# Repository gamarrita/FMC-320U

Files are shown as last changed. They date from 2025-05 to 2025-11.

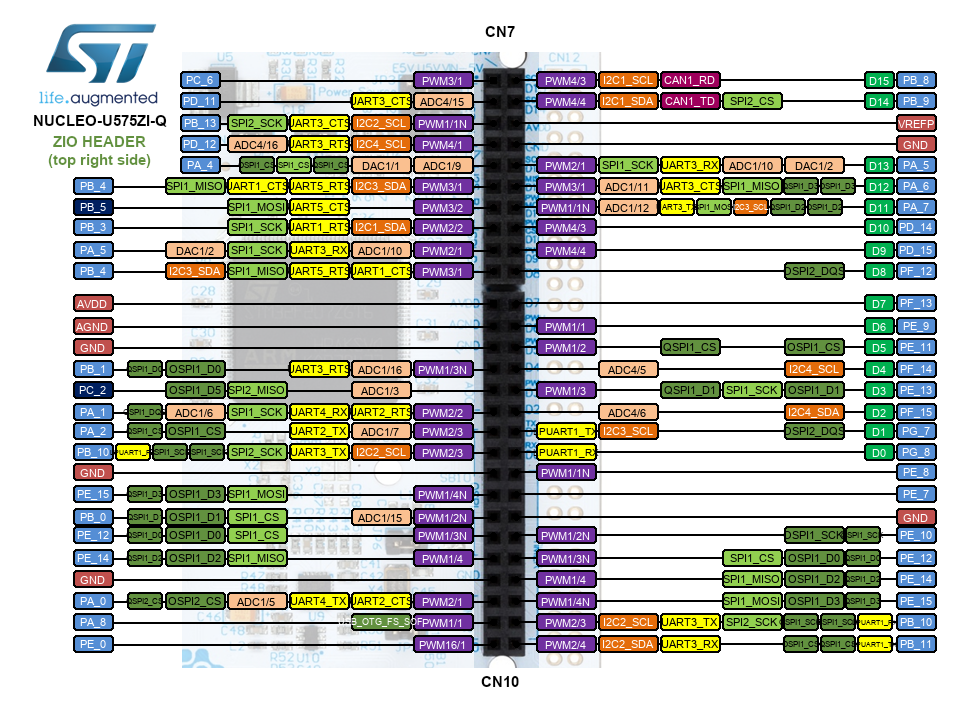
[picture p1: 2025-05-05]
docs/componentes/STM32/nucleo_cn_7_10.png

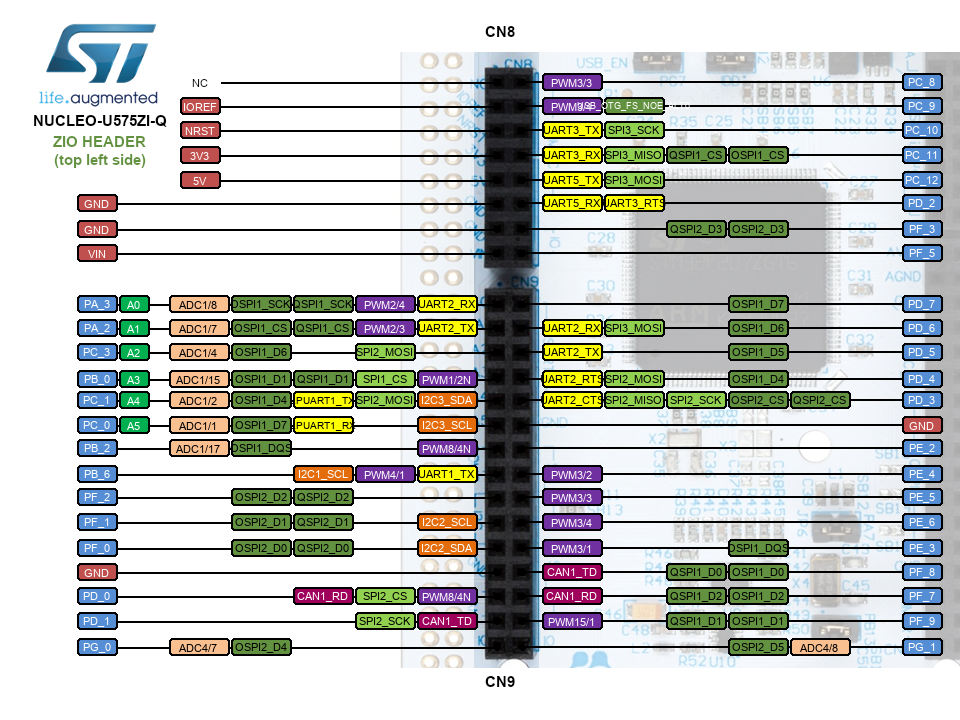
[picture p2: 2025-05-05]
docs/componentes/STM32/nucleo_con_8_9.png

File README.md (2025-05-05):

# FMC-320U: Autonomous Flow Computer

Overview
FMC-320U is an advanced autonomous flow computer designed for precise flow
measurement in industrial applications. It integrates with sensors that emit
pulse signals, processes data in real-time, and provides reliable analytics for
flow monitoring. The system is optimized for ultra-low power consumption,
making it ideal for remote and unattended operations.

Features
- Autonomous Operation: Works independently without requiring external
  computing resources.
- Ultra-Low Power Consumption: Operates with a power consumption of less than
  50µA, making it highly efficient for battery-powered applications. 
- Real-Time Data Processing: Captures and analyzes pulse-based sensor inputs
  efficiently using ThreadX RTOS for optimized multitasking.
- Industrial-Grade Reliability: Ensures accurate and stable performance under
  demanding conditions.
- IoT Capabilities: Supports Wi-Fi and Bluetooth connectivity, enabling remote
  monitoring and data transmission.
- High-Performance Microcontroller: Powered by an STM32F575 microcontroller,
  offering robust computational performance and peripherals for industrial
  applications.
- Data Logging: Includes data logging capabilities to store historical flow
  data for analysis and trend monitoring.
- Modular & Extensible: Easily adaptable to various industrial flow
  measurement scenarios.

Hardware & Firmware
The FMC-320U is built on a robust embedded system, utilizing an STM32F575
ultra-low-power microcontroller optimized for long-term operation. The
firmware is based on ThreadX RTOS, ensuring efficient task management and
real-time data acquisition. Additionally, its IoT features allow seamless
integration with cloud-based monitoring systems.

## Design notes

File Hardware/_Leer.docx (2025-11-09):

Modelo A: formato de PCB rectangular, para cajas EJB0 de la mara TheExZone.

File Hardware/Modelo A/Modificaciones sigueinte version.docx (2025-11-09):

Mejoras de V1R1R1 a V1R2R1 (FINALIZADA)

BUG 1.

Comportamiento: FMC-320U-A2, no alimenta correctamente FMC-320-A1.

Descripción: R2 debería ser de 0 Ohms pero se colocó de 2.49k Ohms, el componente original tenía mal cargado el desginator, error repetido varias veces al crear un componente duplicando uno similar, PCBWAY nota un problema con el footprint y pregunta por cual cambiar, ahí se le pasa un numero de parte erróneo, se corrige un error con otro error.

Solución propuesta: Verificar componente en librería, ver si es necesario actualizar schematic y PCB. Cambiar resistor por uno de 0 Ohms.

Estado: Solucionado

BUG 2.

Comportamiento: el armador del PCB no puede montar componentes x,y,z (completar) los comprados son 0603 y los que se necesitan son 0805.

Descripción: Los componentes (listar componentes) no existían en la biblioteca de Yageo, se los crearon duplicando otros componentes, pero en lugar de duplicar a partir de componentes 0805 se los duplico usando componentes 0603. Notar que al duplicar un componente se deben cambiar necesariamente al menos dos campos, el “Desing Item ID”, pero además el Manufacture “Part Number”, que es el que luego aparece en el BOM.

Solución propuesta: recopilar los ID de números de parte con problemas, corregir librería yageo, actualizar componentes modificados desde la nueva versión de librería (puede que ya este hecho, verificar).

Estado: Solucionado.

BUG 3.

Comportamiento: no funciona el front-end de la salida de pulsos.

Descripción: integrado U1 sin alimentación, el pin 7 que es DVDD del integrado no se conectó.

Solución propuesta: Agregar conexión entre pin 7 u DVDD en el esquemático y routear en PCB. Para las placas prototipos soldar cable entre pin 7 del IC y DVDD

Estado: Solucionado.

BUG 4.

Comportamiento: la corriente en el RTD no es la esperada

Descripción: R16 es 200k cuando debería ser de 100k.

Solución propusta: cambiar el valor de R16 en el laboratorio, verificar funcionamiento, si funciona como lo esperado hacer el cambio en Altium para schematic y PCB.

Estado: Solucionado, se está usando un IC dedicado a la lectura de temperatura.

BUG 5.

Comportamiento: Placa no encaja en gabinete FM-520

Descripción: Los agujeros de fijación están desplazados con respecto a su predecesor FM-500.

Solución: posicionar nuevamente los agujeros de fijación.

Estado: Solucionado, se cambió dimensión de placa, no tiene compatibilidad con antiguo montaje.

BUG 6.

Comportamiento: No se puede medir el consumo del computador correctamente con el programador conectado.

Descripciones: ST-LINK suma 500uA de consumo al computador.

Solución: colocar resistor de cero ohms, solo se colocará en placas de producción.

Estado: Solucionado, se usa una línea exclusiva de alimentación para el ST.LINK.

BUG 7.

Cambiar a baterías AA. Esto se podría considerar como una mejora, pero es de tal importancia que se lo considera un BUG haber usado AAA.

Estado: Solucionado, se cambió a AA.

MEJORA 1.

Descripción: implementar puerto estándar para analizador lógico, o bits + VCC + GND

Solución propuesta: cambiar el valor de R16 en el laboratorio, verificar funcionamiento, si funciona como lo esperado hacer el cambio en Altium para esquemático y PCB.

Estado: Desestimado, se tiene un puerto para ajuste, PD1 a PD4, se lo puede usar para este propósito, hay posibilidad que dada GPIO cumpla doble función, lectura de configuración y señalización o expandir.

MEJORA 2.

Los colores de los LED deben ser:

- LED_1_ERROR usar color rojo
- LED_2 _ACTIVE usar color azul
- LED_3_SIGNAL_1 usar color verde

Estado: Solucionado.

MEJORA 3.

Solo las placas para prototipo tienen lo resistores colocados para los LED. Buscar método para contemplar esto en producción.

Estado: Solucionar por software, los PD1 a PD4 configuran si se prenden o no los LEDs.

MEJORA 4.

Conexión de teclado no tiene acceso, queda bloqueado por la placa 2.

Estado: Solucionado, se cambió a conector a 90°.

VERSIONE ACTUAL

FMC-320U-A1 V1R2R1

FMC-320U-A2 V1R2R1

EMC-3080 V1R1R1

SIGUIENTE VERSIÓN

FMC-320U-A1

FMC-320U-A2

EMC-3080

MODIFICACIÓN #1

Tipo: mejora.

Descripción: para los GPIO usados para los pulsadores externos, incluir filtro RC.

Comportamiento actual:

Comportamiento esperado:

MODIFICACIÓN #2

Tipo: mejora

Descripción: usar borneras para para pulsadores externos.

Comportamiento actual:

Comportamiento esperado:

MODIFICACIÓN #3

Para los GPIO usados para pulsoadores extenos, buscar re-incorprar los dos GPIO perdidos, destinados a configuración y ahora se usan como pulsadores.

MODIFICACIÓN #4

- Lineas RX y TX de UART con pull-up o pull-down. EL

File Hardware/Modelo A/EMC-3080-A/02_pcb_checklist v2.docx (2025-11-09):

Verificación final.

- Repour all polygons -> OK
- Validate PCB Project -> OK
- Verificar que el PCB y el esquemático estén sincronizados -> OK
- Tools -> Desing -> Rule check -> Rulse Desing Rule Check -> OK

Si cualquiera de los anteriores da mal hay volver a iniciar. Si se al verificar cualquiera de los siguientes apartados da mal, volver a iniciar esta verificación.

CARPETAS Y ARCHIVOS.

- Revisar que las carpetas tengan nombres consistentes -> OK
- Revisar que los archivos tengan nombres consistentes -> OK

CREAR EL BOM Y VERIFICAR.

- Manufacturer -> OK
- Manufacturer Part Number -> OK
- Temperatura mínima -> NO APLICA
- Temperatura máxima -> NO APLICA
- Main Supplier ->
- Target Price ->
- No hay dobles valores en ningún campo -> OK

Advertencia: “Design item ID” debe ser el mismo que el Manufacturer part number

TRAZABILIDAD Y DATOS PRINCIPALES.

- El PCB con bordes delimitador en top coutyard -> OK
- Logo de la empresa -> OK
- Legendas de advertencias y peligro -> NO APLICA
- Correo y web de la empresa -> OK
- Nombre de la placa -> OK
- Número de serie, versión y revisión -> OK
- Área para número de serie -> NO APLICA
- Numero de lote -> OK
- Area para re-work -> NO APLICA
- Área para control de calidad -> NO APLICA
- Medidas de la placa en mechanical layer -> OK
- Rotulo con información en mechancal layer -> OK
- Notas sobre catodos, polaridades, etc. en mechanial layers -> OK

TOP Y BOTTOM OVERLAY.

- Designator : tamaño sugerido 1.25mm(alto)/0.25mm(grosor). Para textos que no estén horizontal usar solo un sentido vertical, sugerido arriba hacia abajo. El tamaño de 1.0mm(alto)/0.2mm(grosor) también es aceptable.
- Designators cerca de los componentes.
- IC con pin 1 claramente marcado

Los siguientes puntos de verificación se deben hacer sobre una planilla Excel que controlo cada componente.

Puertos de comunicación:

- Conexión de RX y TX cruzadas.
- Resistores de terminación calculados.
- Resistores en serie con líneas de transmisión con alto rise time y baja tasa de transferencia. Esto también aplica para comparadores y otras líneas que puedan mantenerse como sistema de parámetros concentrados.

Montaje

- Elementos mecánicos incluidos con sus modelos 3D.
- Gabinete y modelo 3D incluido

Diseño.

- Se usaron reglas estándar del fabricante -> OK
- Reglas de diseño al menos un 15% por encima de las del fabricante. -> OK
- Circuito de parámetros concentrados -> OK
- Todas las conexiones a GND con via GND copper pour -> OK
- Vías con suficiente capacidad de corriente ->
- Pistas con suficiente capacidad de corriente ->
- Componentes sin excesivo aumento de temperatura (check list en Excel) ->

Conectores

- Conectores inter-placas estén bien mapeados -> OK
- Pin 1 para Alimentación y pin 2 para GND (check list Excel) -> Regla obsoleta no se usa.
- Capacitores de desacople en los pines de alimentación (check list Excel) ->
- Conectores con CN (check list Excel) ->
- Jumpers con J (check list Excel) ->
- Altura de los conectores inter-placa sea la correcta (check list Excel) ->

BORNERAS USUARIO.

- Designators nombre sugerido P? (check list Excel) ->
- Designators tamaño sugerido 2mm / 0.4mm (check list Excel) ->
- Salidas marcadas (check list Excel) ->

CIRCUITOS INTEGRADOS.

- Alimentaciones -> OK
- Tierras -> OK
- Validado por nota de aplicación o uso anterior-> OK

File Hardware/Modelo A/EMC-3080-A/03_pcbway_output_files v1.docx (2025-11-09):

ESTE DOCUMENTO MUESTRA COMO SE PREPARAN LOS ARCHIVOS PARA ENVIAR A PCBWAY

Copiar trunk a tag, eliminar archivos no necesarios o los de salida previamente generados.

Copiar carpeta Sources

Se deben generar tres salidas:

Gerbers y Drills para PCBWAY van juntos.

Se utilizan en la fabricación del PCB. Se generan por separado, pero se comprimen en un único archivo. Links de referencia:

https://www.pcbway.es/helpcenter/technical_support/Generate_gerber_file_from_Altium.html

Centroid files (Pick&Place).

Se utilizan para la fabricación del PCB. Se comprimen junto con los gerbres

https://www.pcbway.com/helpcenter/technical_support/How_to_create_a_Centroid_File_from_Eagle__Altium_Sprint_Layout_and_ORCAD_.html

Generar Gerbers.

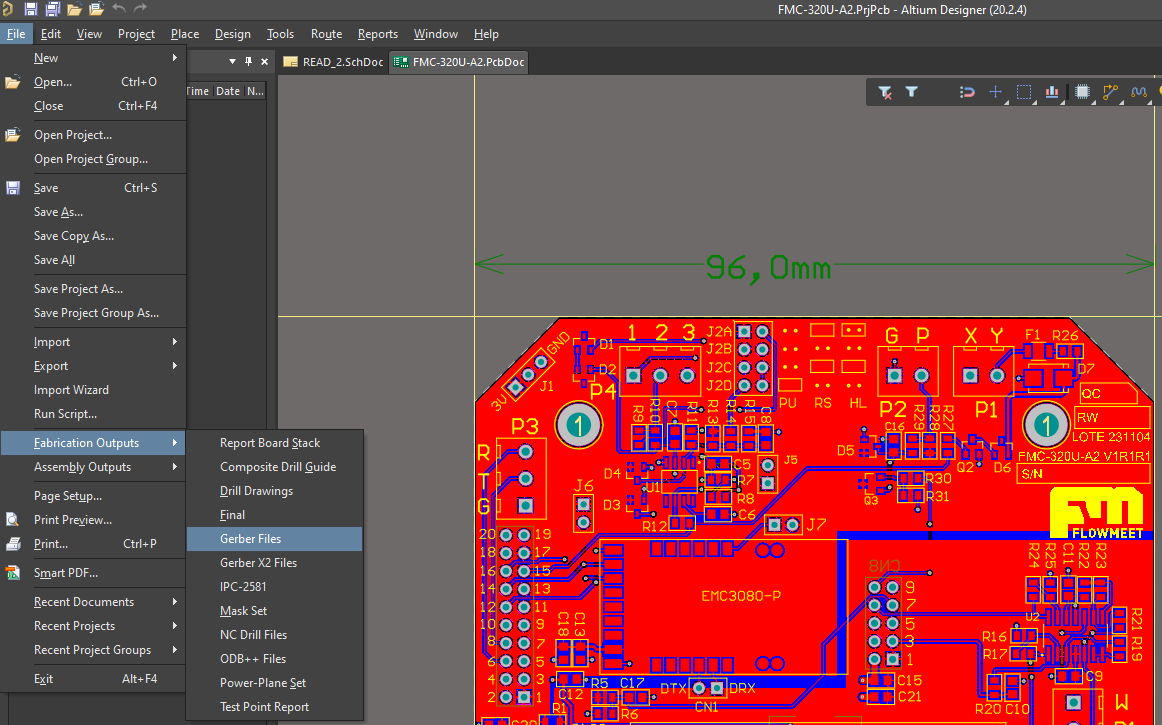
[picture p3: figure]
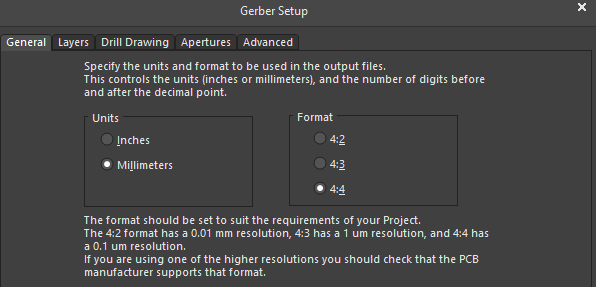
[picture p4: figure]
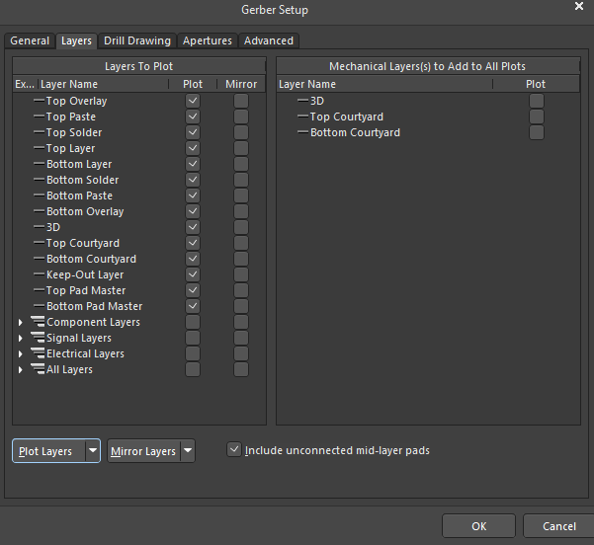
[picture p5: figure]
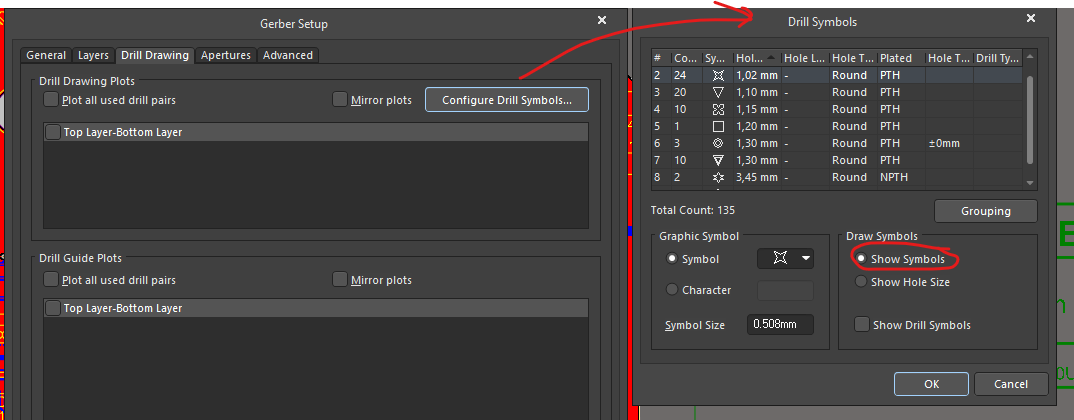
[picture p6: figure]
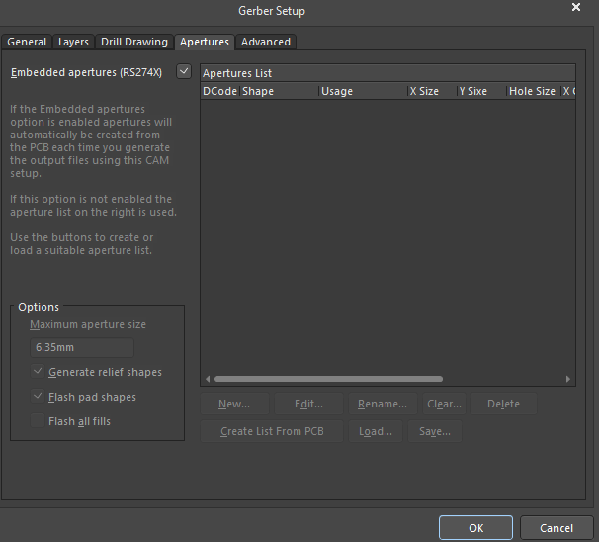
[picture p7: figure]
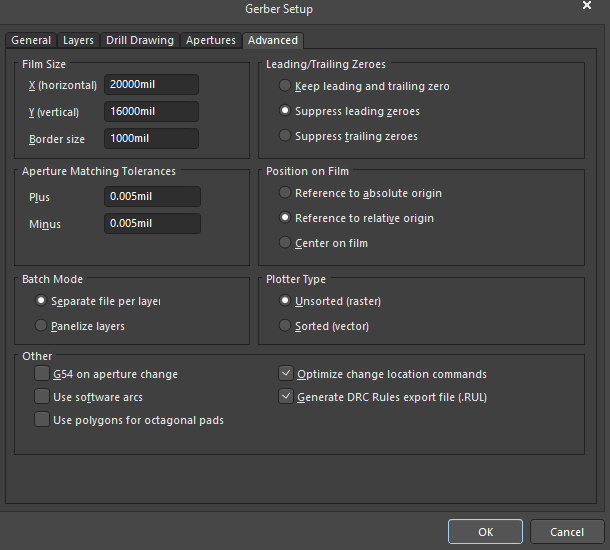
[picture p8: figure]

Generar Drills.

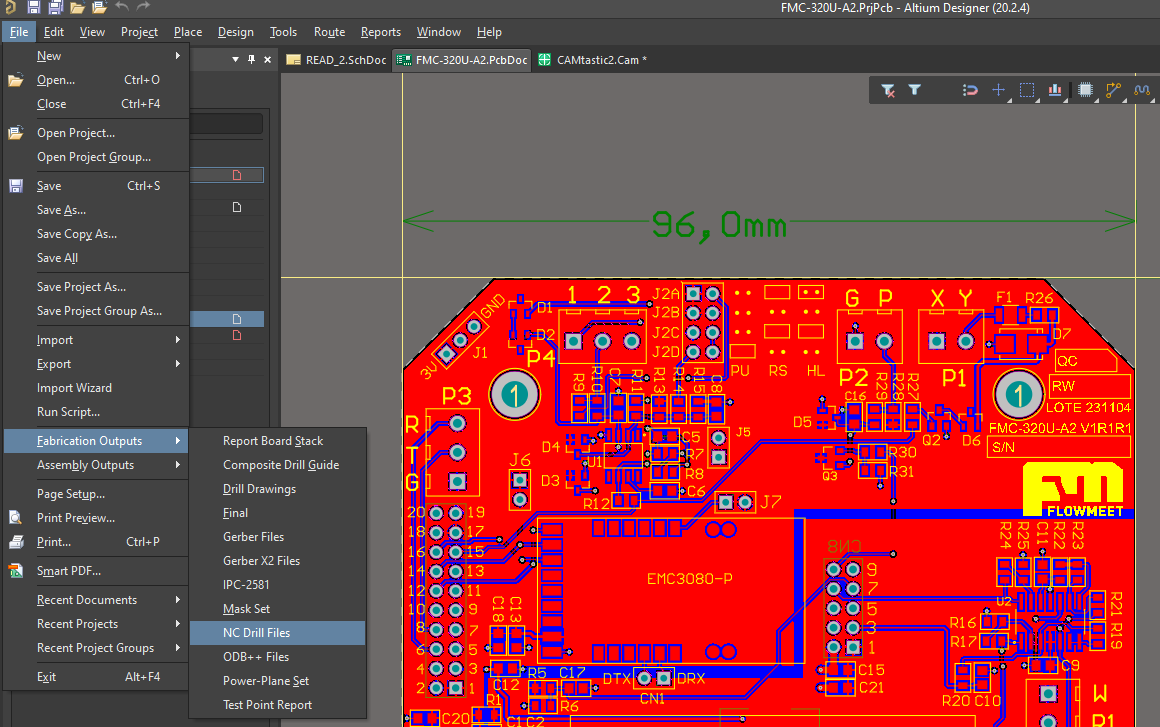
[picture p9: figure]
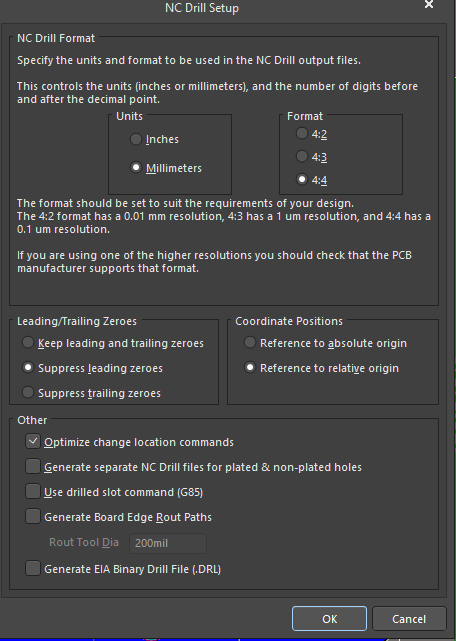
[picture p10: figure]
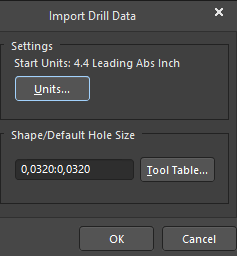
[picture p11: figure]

Pick&Place

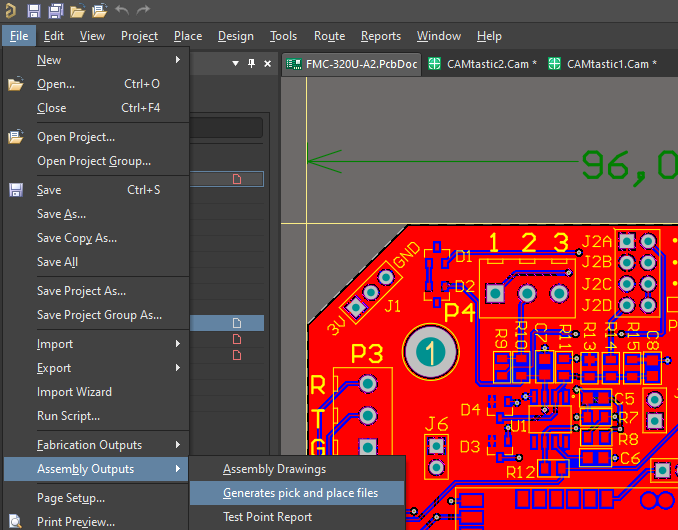
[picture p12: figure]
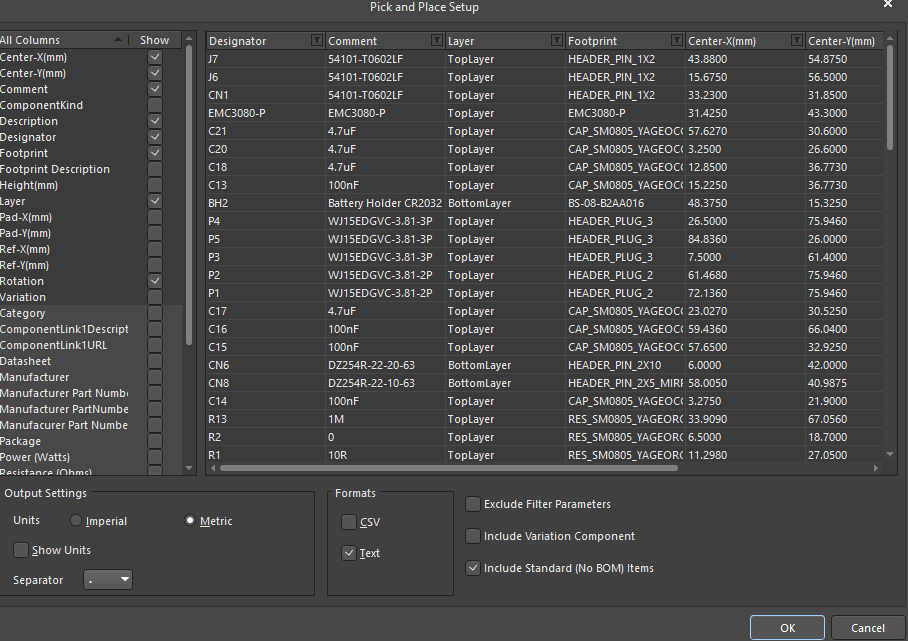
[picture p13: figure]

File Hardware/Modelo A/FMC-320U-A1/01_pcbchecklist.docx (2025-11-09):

Verificación final.

- Repour all polygons -> LISTO
- Validate PCB Project -> LISTO
- Verificar que el PCB y el esquemático estén sincronizados -> LISTO
- Tools -> Desing -> Rule check -> Rulse Desing Rule Check -> LISTO

Si cualquiera de los anteriores da mal hay volver a iniciar. Si se al verificar cualquiera de los siguientes apartados da mal, volver a iniciar esta verificación.

Carpetas y archivos.

- Revisar que las carpetas tengan nombres consistentes -> LISTO
- Revisar que los archivos tengan nombres consistentes -> LISTO

Trazabilidad y datos principales

- Logo de la empresa -> LISTO
- Legendas de advertencias y peligro -> NO APLICA
- Correo y web de la empresa -> NO APLICA
- Nombre de la placa -> LISTO
- Número de serie, versión y revisión -> LISTO
- Área para número de serie -> LISTO
- Numero de lote -> LISTO
- Area para re-work -> LISTO
- Área para control de calidad -> LISTO

Top y Bottom Overlay.

- Designator 3en tamaño 1.25mm(alto)/0.25mm(grosor). Para textos que no estén horizontal usar solo un sentido vertical, sugerido arriba hacia abajo.
- Designators cerca de los componentes.
- IC con pin 1 claramente marcado

Montaje

- Incluir tornillos, arandelas, separadores y tuercas, verificar que haya suficiente espacio para el montaje.
- Incluir modelo 3D del gabinete.

Diseño.

- Siempre que sea posible trabajar con las reglas estándar del fabricante. Apártese de esto requiere autorización.
- Ajustar las reglas de diseño un 15% por encima de las del fabricante. Solo usar espacio o grosores igual las mínimas estándar del fabricante si es totalmente necesario.
- Verificar si se esta trabajando con un circuito de parámetros distribuidos o concentrados.
- En parámetros concentrados como norma general usar lo mayor posibles componentes SMD, routeado mayormente en lado top y bottom con buen copper pour de GND. Lado top puede requerir copper pour para las alimentaciones.
- Todas las conexiones a GND con via GND copper pour.
- Vías con suficiente capacidad de corriente.
- Pistas con suficiente capacidad de corriente.
- Componentes sin excesivo aumento de temperatura.

verificación de parámetros concentrado.

No hay en esta placa.

Conectores

- Verificar que conectores inter-placas estén bien mapeados.
- Como regla general usar pin 1 para Alimentación y pin 2 para GND.
- Capacitores de desacople en los pines de alimentación.
- Conectores con CN.
- Jumpers con J.
- Verificar que la altura de los conectores inter-placa sea la correcta

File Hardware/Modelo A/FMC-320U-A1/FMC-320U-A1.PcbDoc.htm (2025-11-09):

Reporting Options

# File in Newer Format

Date | : | 30/11/2024
Time | : | 10:57:01
Filename | : | D:\FLOWMEET Dropbox\flowmeet\ID\Electronica\Equipos\FMC-320U\hardware\altium\model_a\trunk\FMC-320U-A1\FMC-320U-A1.PcbDoc

Version | Warning
Release 23.6 | CAUTION - The PCB document contains Footprint parameters. These will be lost when opening the document in a version of Altium Designer that does not support this functionality.

This file was generated by a later version of the software

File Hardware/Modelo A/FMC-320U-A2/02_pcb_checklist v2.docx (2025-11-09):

Modificaciones

28/11/2023 - DHS: agrego verificación entre Desing Item ID y Manufacturar part number

Descripcion: Este documento es check list de PCB creado en Altium Designer necesario de completar antes de enviar a fabricar a PCBWAY. Describe los pasos a seguir cuando la etapa de diseño esté terminada. Antes de iniciar el proceso de pedido de cotización se deben pasar todas las verificaciones. Este documento se debe trabajar en conjunto con el 01_components_check_list. Luego debe seguir las instrucciones del documento se ejecuta el 03_pcway_output_files, se genera la carpeta versionada y archivos para enviar al fabricante de placas.

Verificación final.

- Repour all polygons ->
- Validate PCB Project ->
- Verificar que el PCB y el esquemático estén sincronizados ->
- Tools -> Desing -> Rule check -> Rulse Desing Rule Check ->

Si cualquiera de los anteriores da mal hay volver a iniciar. Si se al verificar cualquiera de los siguientes apartados da mal, volver a iniciar esta verificación.

CARPETAS Y ARCHIVOS.

- Revisar que las carpetas tengan nombres consistentes ->
- Revisar que los archivos tengan nombres consistentes ->

CREAR EL BOM Y VERIFICAR.

- Designator ->
- Quantity ->
- Manufacturer ->
- Manufacturer Part Number ->
- Temperatura mínima ->
- Temperatura máxima ->
- Main Supplier ->
- Target Price ->

Advertencia : “Design item ID” debe ser el mismo que el Manufacturer part number.

TRAZABILIDAD Y DATOS PRINCIPALES.

- El PCB con bordes delimitador en top coutyard ->
- Logo de la empresa -> OK
- Legendas de advertencias y peligro -> NO APLICA
- Correo y web de la empresa -> NO APLICA
- Nombre de la placa -> OK
- Número de serie, versión y revisión -> OK
- Área para número de serie -> OK
- Numero de lote -> OK
- Area para re-work -> OK
- Área para control de calidad -> OK
- Medidas de la placa en mechanical layer -> OK
- Rotulo con información en mechancal layer -> OK
- Notas sobre catodos, polaridades, etc. en mechanial layers -> OK

TOP Y BOTTOM OVERLAY.

- Designator : tamaño sugerido 1.25mm(alto)/0.25mm(grosor). Para textos que no estén horizontal usar solo un sentido vertical, sugerido arriba hacia abajo. El tamaño de 1.0mm(alto)/0.2mm(grosor) también es aceptable.
- Designators cerca de los componentes.
- IC con pin 1 claramente marcado

Los siguientes puntos de verificación se deben hacer sobre una planilla Excel que controlo cada componente.

Puertos de comunicación:

- Conexión de RX y TX cruzadas.
- Resistores de terminación calculados.
- Resistores en serie con líneas de transmisión con alto rise time y baja tasa de transferencia. Esto también aplica para comparadores y otras líneas que puedan mantenerse como sistema de parámetros concentrados.

Montaje

- Elementos mecánicos incluidos con sus modelos 3D.
- Gabinete y modelo 3D incluido

Diseño.

- Se usaron reglas estándar del fabricante -> OK
- Reglas de diseño al menos un 15% por encima de las del fabricante. -> OK
- Circuito de parámetros concentrados -> OK
- Todas las conexiones a GND con via GND copper pour -> OK
- Vías con suficiente capacidad de corriente ->
- Pistas con suficiente capacidad de corriente ->
- Componentes sin excesivo aumento de temperatura (check list en Excel) ->

Conectores

- Conectores inter-placas estén bien mapeados (check list Excel) ->
- Pin 1 para Alimentación y pin 2 para GND (check list Excel) ->
- Capacitores de desacople en los pines de alimentación (check list Excel) ->
- Conectores con CN (check list Excel) ->
- Jumpers con J (check list Excel) ->
- Altura de los conectores inter-placa sea la correcta (check list Excel) ->

BORNERAS USUARIO.

- Designators nombre sugerido P? (check list Excel) ->
- Designators tamaño sugerido 2mm / 0.4mm (check list Excel) ->
- Salidas marcadas (check list Excel) ->

CIRCUITOS INTEGRADOS.

- Alimentaciones ->
- Tierras ->
- Validado por nota de aplicación o uso anterior->

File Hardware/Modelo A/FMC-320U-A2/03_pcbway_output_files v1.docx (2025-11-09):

ESTE DOCUMENTO MUESTRA COMO SE PREPARAN LOS ARCHIVOS PARA ENVIAR A PCBWAY

Se hace un realese del projecto. Con los archivos generados se crea el tag.

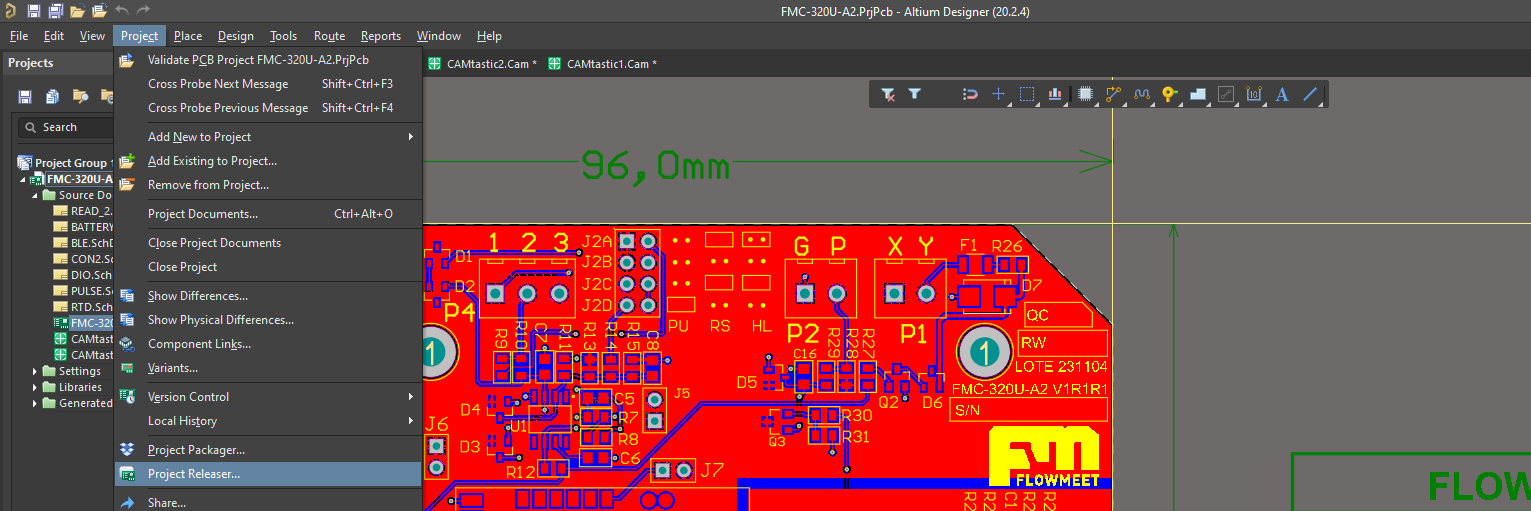
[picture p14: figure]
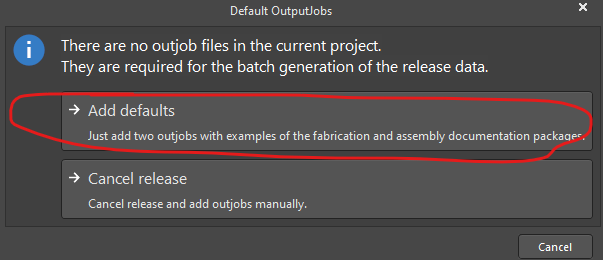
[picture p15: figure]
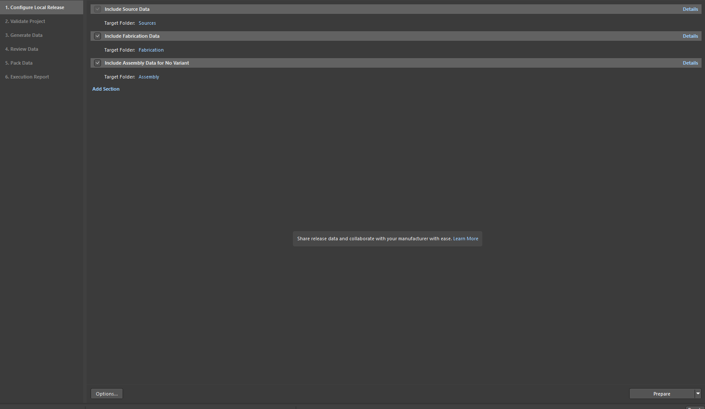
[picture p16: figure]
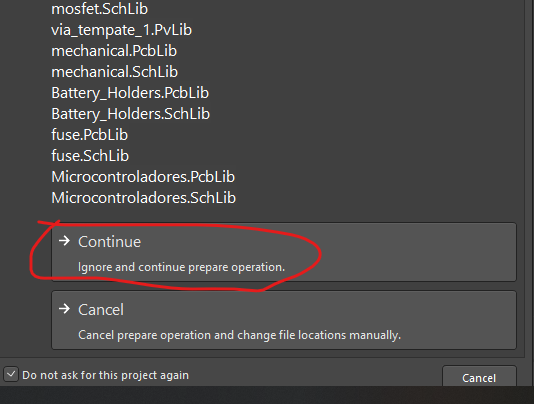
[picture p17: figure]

Copiar carpeta Sources

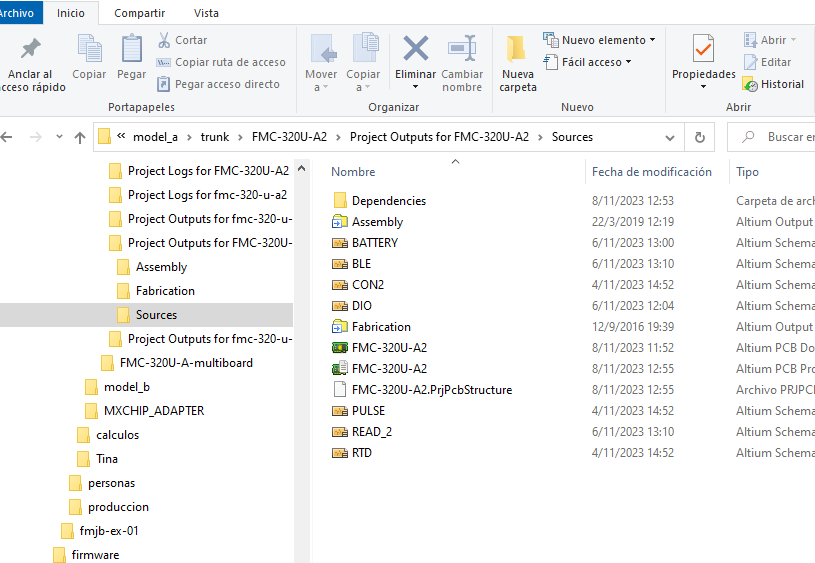
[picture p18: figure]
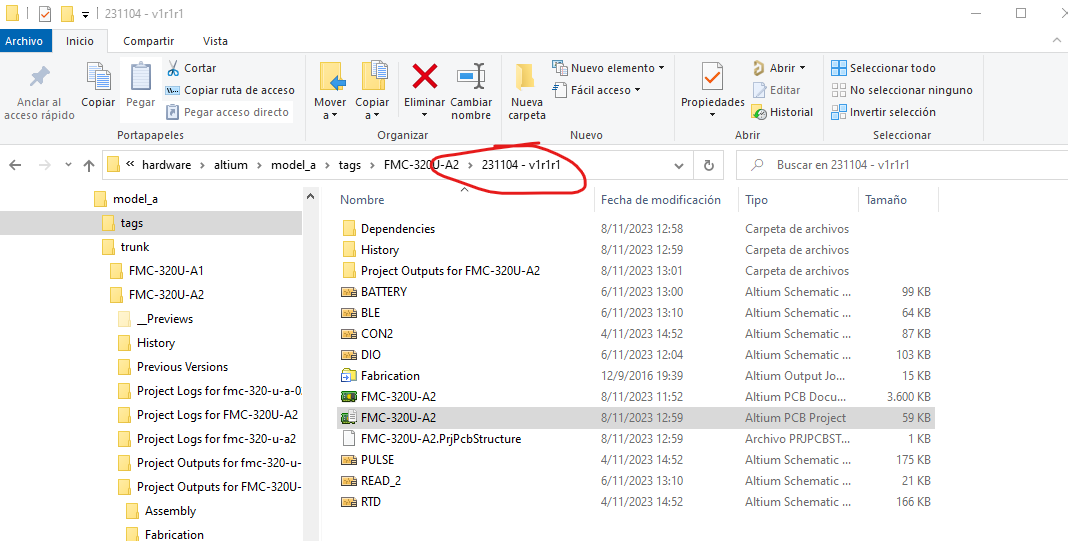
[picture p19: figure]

Se deben generar tres salidas:

Gerbers y Drills

Se utilizan en la fabricación del PCB. Se generan por separado pero se comprimen en un único archivo. Links de referencia:

https://www.pcbway.es/helpcenter/technical_support/Generate_gerber_file_from_Altium.html

Centroid files (Pick&Place).

Se utilizan para la fabricación del PCB. Se comprimen junto con los gerbres

https://www.pcbway.com/helpcenter/technical_support/How_to_create_a_Centroid_File_from_Eagle__Altium_Sprint_Layout_and_ORCAD_.html

Generar Gerbers.


Generar Drills.


Pick&Place


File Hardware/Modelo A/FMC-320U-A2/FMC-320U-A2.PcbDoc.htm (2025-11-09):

Reporting Options

# File in Newer Format

Date | : | 30/11/2024
Time | : | 10:57:06
Filename | : | D:\FLOWMEET Dropbox\flowmeet\ID\Electronica\Equipos\FMC-320U\hardware\altium\model_a\trunk\FMC-320U-A2\FMC-320U-A2.PcbDoc

Version | Warning
Release 23.6 | CAUTION - The PCB document contains Footprint parameters. These will be lost when opening the document in a version of Altium Designer that does not support this functionality.
Release 24.4 | CAUTION - This PCB document contains polygon pours with the "Obey Rules" option enabled. If you save the PCB document in this older version, the "Obey Rules" option will be turned off for these polygon pours.

This file was generated by a later version of the software

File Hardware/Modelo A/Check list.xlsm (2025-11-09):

Fuente: | https://resources.altium.com/p/pcb-design-and-review-checklist
 | https://www.volersystems.com/blog/design-tips/91-pcb-layout-checklist
 | FINAL REVIEW | Check
 | Reglas de diseño + 20% minimo | OK
 | Recontruir poligonos de areas de llenado | OK
 | Logo de la empresa | OK
 | Advertencias en skill layer, ejemplo alta tension. | NO LLEVA
 | Nombre de la plata | OK
 | Numero de lote | OK
 | Area para el numero de serie | NO LLEVA
 | Area version, revision releas. Area par re-work | NO LLEVA
 | Conectores y borneras con sus etiquetas | NO LLEVA
 | Area QC | NO LLEVA
 | Designator cerca de los compoentes, en solo una o dos direcciones | OK
 | BOM verificar numero de parte de fabricante | OK
 | PCB sincronizado con esquematico | OK
 | Reporte de reglas sin errores- estandarizar relaglas | OK
 | Una regla que advierte de nets con un solo pin | OK
 | Una mecanica layer que indique los limites de la placa, top assembly? | OK
 | Dimensiones en mecanical layer | OK
 | Para placas sueltas agrega al menos dos fiducial en posiciones opuetas | NO LLEVA
 | Puntos de montaje con despeje suficiente para arandelas, tornillos, tuercas, etc | OK
 | Todos los componentes con modelos 3D | OK
 | Gabienete con modelo 3D | NO LLEVA
 | El armado y conexcionado verificado por los modelos 3D y maquetas. | NO SE HIZO
 | LAYERS | Check
 | Verificar si se esta en el modelo concentrado o distribido | CONCENTRADO
 | Para modelo distribuido al menos un plano de tierra continuo por signal layer | NO LLEVA
 | SIGNAL PATH | Check
 | Mantener componentes analogicos y digitales en areas separadas | OK
 | Separar AVDD DVDD. | OK
 | Verificar ancho de pistas y consumo de corriente | NO SE HIZO
 | Verificar que hay suficiente vias para conducir la corriente | NO SE HIZO
 | Pistas diferenciales cercanas y simetria | NO LLEVA
 | Largo de pistas > 16th rise/fall time agregar condiciones liena de transmision | NO SE HIZO
 | Capacitores de desacoble no compatiros | OK
 | COMPONENTS | Check
 | Verificar que la geometria de pad tenga mascara anti-soldante | OK
 | Verificar que haya suficiente despeje para el aramdo humano y maquina | OK
 | Capacitores de desacople a 15mm o menos de los pines | OK
 | Verificar que los osciladores esten lo mas cerca posible de los osciladores | OK
 | Resistores de terminacion tan cerca de la fuente de señal como sea posible | NO SE HIZO
 | Filtro EMI/RFI cerca de los puntos de conexión. | NO LLEVA
 | Intreface humana se implementa de la forma mas estandar. | OK
 | Dispositivos programable con facil acceso | OK
 | Verifcar que fuente de disipacion de calor no esten cerca de pequeñso componentes | NO LLEVA
 | Verificar que la ubicaciones de componentes priorice pistas cortas de alta frecuencia. | NO SE HIZO
 | Check there is a sufficiently large copper area for heat sinking high dissipation devices, including: · Linear regulators · Switched-mode power supplies (including LED drivers) · High power LEDs · High-frequency gate drivers · MOSFETs · Motor drivers · Chargers · High-speed microprocessors · Power amplifiers | NO LLEVA
 | TESTING | Check
 | Las reglas escritas estaban pensadas para cama de clavos. Entiendo que lo que obtendremos por ahora es inspeccion optica. Ver si hay un conjunto de reglas para esta tecnica
 | PROTECTION/EMI/EMC | Check
 | Check appropriate creepage and clearance rules are set for all high voltage nets
 | Check if separate earth tracks/paths are necessary for ESD
 | Check there are decoupling capacitors next to connectors and vias that may require them
 | Check TVS diodes or other ESD mitigation component pads are in series with the track to the component (i.e., any ESD event must pass through the component pad before getting to a sensitive device)
 | Ensure there are no track stubs/net antennas going to test points or unused connector pins
 | Ensure high-speed signals are routed as directly as possible—no scenic routes
 | Check any track carrying over 100mA has its width calculated to ensure it is of sufficient size for the current · If the board will be fitted within an enclosure with little or no airflow, calculate or simulate the width for an internal layer instead of an external layer
 | Check if an RF shield is required anywhere on the board and if it has a sufficient footprint
 | If you are using a two-layer board: · Are there any ground loops? · Is there a ground track of sufficient size for the return current of every device? · Is there an unbroken ground pour under every high-speed trace?
 | If you have multiple grounds, ensure that they are tied together at a single point only
 | PANELS | Check
 | Ensure that there is sufficient frame area for conveyors and clamping
 | Ensure that the silkscreen includes the following: · Blanks for QA/Testing marks · Print date · Machine name · Company name · Panel barcode · Board part number and revision
 | Check panel fiducials are present
 | Check for an origin identification mark
 | Check impedance/layer/other test areas are present if required
 | Check V Score/Milling/tab layers are present and aligned with the board if they are not in the board file
 | Check the panel isn't too large for the board thickness and any milling (i.e., low flexibility/bounce)

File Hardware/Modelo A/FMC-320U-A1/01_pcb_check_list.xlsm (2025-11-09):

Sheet: Sheet1
Nomnre de Archivos
 | Revisar que sean coherentes en el proyecto y carpetas
S

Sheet: parcial
Fuente: | https://resources.altium.com/p/pcb-design-and-review-checklist
 | https://www.volersystems.com/blog/design-tips/91-pcb-layout-checklist
 | Item
 |  | Aplica | Pasa | Observacion
 |  | Check
 | Check traces longer than 1/6th of the rise or fall time of the signal have been simulated:
 | Check all high-speed traces run over a continuous ground pour
 | Ensure that no sensitive nets run under noisy components
 | Each decoupling capacitor requires its own via for VCC and for GND direct to reference planes
 | Check all through-hole pads are set to plated if they are going to be soldered
 | Check there is sufficient clearance for pick and place heads in production
 | Check there is sufficient clearance for hand assembly in prototypes
 | Check there is sufficient clearance for soldering pen tip access if any rework is required
 | Check bypass capacitors are placed as close to IC power pins as possible (under 15mm)
 | Check crystal/oscillator clock sources are as close to the IC clock pins as possible
 | Check termination resistors are as close to the signal source as possible
 | Check EMI/RFI filtering is as close to the exit point (board edge, connector, shield) as possible
 | Check potentiometers increase signal/voltage when turned clockwise
 | Check programmable devices have accessible programming header/pads
 | Check no high thermal mass components (e.g., large transformers/inductors) are located next to very small components
 | Check component placement prioritizes short track lengths for high-speed signals
 | Check there is a sufficiently large copper area for heat sinking high dissipation devices
 | Check appropriate creepage and clearance rules are set for all high voltage nets
 | Check if separate earth tracks/paths are necessary for ESD
 | Check TVS diodes or other ESD mitigation component pads are in series with the track to the component (i.e., any ESD event must pass through the component pad before getting to a sensitive device) | Check
 |  | Check
 | Check TVS diodes or other ESD mitigation component pads are in series with the track to the component (i.e., any ESD event must pass through the component pad before getting to a sensitive device)
 | Ensure there are no track stubs/net antennas going to test points or unused connector pins
 | Ensure high-speed signals are routed as directly as possible—no scenic routes
 | Check any track carrying over 100mA has its width calculated to ensure it is of sufficient size for the current · If the board will be fitted within an enclosure with little or no airflow, calculate or simulate the width for an internal layer instead of an external layer
 | Check if an RF shield is required anywhere on the board and if it has a sufficient footprint
 | If you are using a two-layer board: · Are there any ground loops? · Is there a ground track of sufficient size for the return current of every device? · Is there an unbroken ground pour under every high-speed trace?
 | If you have multiple grounds, ensure that they are tied together at a single point only
 | PANELS | Check
 | Ensure that there is sufficient frame area for conveyors and clamping
 | Ensure that the silkscreen includes the following: · Blanks for QA/Testing marks · Print date · Machine name · Company name · Panel barcode · Board part number and revision
 | Check panel fiducials are present
 | Check for an origin identification mark
 | Check impedance/layer/other test areas are present if required
 | Check V Score/Milling/tab layers are present and aligned with the board if they are not in the board file
 | Check the panel isn't too large for the board thickness and any milling (i.e., low flexibility/bounce)

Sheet: full
Fuente: | https://resources.altium.com/p/pcb-design-and-review-checklist
 | https://www.volersystems.com/blog/design-tips/91-pcb-layout-checklist
 | FINAL REVIEW | Check
 | Reglas de diseño + 20% minimo
 | Recontruir poligonos de areas de llenado
 | Logo de la empresa
 | Advertencias en skill layer, ejemplo alta tension.
 | Nombre de la placa
 | Informacion de lote
 | Area para el numero de serie
 | Area version, revision releas. Area par re-work
 | Conectores y borneras con sus etiquetas
 | Area QC
 | Designator cerca de los compoentes, en solo una o dos direcciones
 | Componentes cargado en el excel listado
 | PCB sincronizado con esquematico
 | Reporte de reglas sin errores- estandarizar relaglas
 | Una regla que advierte de nets con un solo pin
 | Una mecanica layer que indique los limites de la placa, top assembly?
 | Para placas sueltas agrega al menos dos fiducial en posiciones opuetas
 | Puntos de montaje con despeje suficiente para arandelas, tornillos, tuercas, etc
 | Todos los componentes con modelos 3D
 | Gabienete con modelo 3D
 | El armado y conexcionado verificado por los modelos 3D y maquetas.
 | LAYERS | Check
 | Verificar si se esta en el modelo concentrado o distribido
 | Para modelo distribuido al menos un plano de tierra continuo por signal layer
 | SIGNAL PATH | Check
 | Mantener componentes analogicos y digitales en areas separadas
 | Separar AVDD DVDD, AGND y DNG se unen cerca del regulador/bateria
 | Verificar ancho de pistas y consumo de corriente
 | Verificar que hay suficiente vias para conducir la corriente
 | Pistas diferenciales cercanas y simetria
 | Largo de pistas > 16th rise/fall time agregar condiciones liena de transmision
 | Capacitores de desacoble no compatiros
 | COMPONENTS | Check
 | Verificar que la geometria de pad tenga mascara anti-soldante
 | Verificar que haya suficiente despeje para el aramdo humano y maquina
 | Capacitores de desacople a 15mm o menos de los pines
 | Verificar que los osciladores esten lo mas cerca posible de los osciladores
 | Resistores de terminacion tan cerca de la fuente de señal como sea posible
 | Filtro EMI/RFI cerca de los puntos de conexión.
 | Intreface humana se implementa de la forma mas estandar.
 | Dispositivos programable con facil acceso
 | Verifcar que fuente de disipacion de calor no esten cerca de pequeñso componentes
 | Verificar que la ubicaciones de componentes priorice pistas cortas de alta frecuencia.
 | Check there is a sufficiently large copper area for heat sinking high dissipation devices, including: · Linear regulators · Switched-mode power supplies (including LED drivers) · High power LEDs · High-frequency gate drivers · MOSFETs · Motor drivers · Chargers · High-speed microprocessors · Power amplifiers
 | TESTING | Check
 | Las reglas escritas estaban pensadas para cama de clavos. Entiendo que lo que obtendremos por ahora es inspeccion optica. Ver si hay un conjunto de reglas para esta tecnica
 | PROTECTION/EMI/EMC | Check
 | Check appropriate creepage and clearance rules are set for all high voltage nets
 | Check if separate earth tracks/paths are necessary for ESD
 | Check there are decoupling capacitors next to connectors and vias that may require them
 | Check TVS diodes or other ESD mitigation component pads are in series with the track to the component (i.e., any ESD event must pass through the component pad before getting to a sensitive device)
 | Ensure there are no track stubs/net antennas going to test points or unused connector pins
 | Ensure high-speed signals are routed as directly as possible—no scenic routes
 | Check any track carrying over 100mA has its width calculated to ensure it is of sufficient size for the current · If the board will be fitted within an enclosure with little or no airflow, calculate or simulate the width for an internal layer instead of an external layer
 | Check if an RF shield is required anywhere on the board and if it has a sufficient footprint
 | If you are using a two-layer board: · Are there any ground loops? · Is there a ground track of sufficient size for the return current of every device? · Is there an unbroken ground pour under every high-speed trace?
 | If you have multiple grounds, ensure that they are tied together at a single point only
 | PANELS | Check
 | Ensure that there is sufficient frame area for conveyors and clamping
 | Ensure that the silkscreen includes the following: · Blanks for QA/Testing marks · Print date · Machine name · Company name · Panel barcode · Board part number and revision
 | Check panel fiducials are present
 | Check for an origin identification mark
 | Check impedance/layer/other test areas are present if required
 | Check V Score/Milling/tab layers are present and aligned with the board if they are not in the board file
 | Check the panel isn't too large for the board thickness and any milling (i.e., low flexibility/bounce)

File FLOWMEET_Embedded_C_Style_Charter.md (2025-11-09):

# FLOWMEET Embedded C Style v1.0 (Charter)

## Propósito
Unificar el estilo de firmware en FLOWMEET para el proyecto FMC-320U, de forma que tanto programadores humanos como herramientas de IA puedan aplicar reglas claras, consistentes y verificables.

## Jerarquía de Normas
1. Este documento: **FLOWMEET Embedded C Style v1.0 (Charter)**.
2. Guías internas de detalle:  
   - `STYLE_GUIDE_FIRMWARE_NAMING.md` (nombres).  
   - `STYLE_GUIDE_FIRMWARE_COMMENTS.md` (comentarios, encabezados, secciones).  
   - `STYLE_GUIDE_FIRMWARE_CONCURRENCY.md` (concurrencia e ISR) *(opcional)*.
3. Documentación oficial de STM32Cube/HAL/ThreadX (cuando el prototipo o callback lo requiera).
4. Referencias externas: Barr Group Embedded C, MISRA C:2012 (subset esencial), NASA/JPL C, Google C Style Guide (solo para formato cuando no exista regla interna).
5. `.clang-format` oficial del repositorio (enforcement automático).

## Principios Clave
- **Consistencia sobre preferencia.**
- **Respetar APIs de terceros**: no renombrar HAL/ThreadX.
- **C portátil y seguro**: tipos explícitos (`uint32_t`), evitar casts implícitos.
- **Legibilidad**: 80 columnas, ASCII, voz activa en comentarios.
- **Compatibilidad futura**: reservar espacio en estructuras y registros críticos.

## Estructura de Archivos
- Encabezado obligatorio con Doxygen (`@file`, `@brief`).  
- Secciones internas estándar:  
  `// --- Includes ---`, `// --- Defines ---`, `// --- Types ---`,  
  `// --- Globals ---`, `// --- Static Data ---`, `// --- Public API ---`,  
  `// --- Static Functions ---`, `// --- Interrupts ---`.  
- Cierre obligatorio:  
  ```
  /*** END OF FILE ***/
  ```

## Nombres
- Archivos: `fm_modulo.c`, `fmx_modulo.c`.  
- API pública: `FM_MOD_Action`, `FMX_Action`.  
- Internas estáticas: `CamelCase` sin prefijo.  
- Tipos: `fm_mod_state_t`, `fmx_context_t`.  
- Macros: mayúsculas con prefijo (`FM_LOG_BUFFER_SIZE`).  
- Variables:  
  - Exportadas: `FM_LOG_QueueDepth`.  
  - Estáticas: `static uint8_t pulse_flag;`.  
  - Automáticas/params: `raw_count`.  
- Booleanas: sufijo `_flag`, `_enable`, `_active`.

## Concurrencia y RTOS
- ISRs: no bloquear, no malloc, diferir trabajo a tareas.  
- Comunicación: siempre por `TX_QUEUE` o event flags.  
- Documentar prioridades y tamaños de stack en headers.

## Política de Errores y Logs
- Tipo único `fm_status_t`.  
- No errores silenciosos: log o assert configurable.  
- Para logging persistente: buffer en RAM, flush por bloque, reservar 16 bytes de compatibilidad futura.

## Enforcement
- `.clang-format` obligatorio.  
- `clang-tidy` + `cppcheck` + MISRA subset en CI.  
- Revisión de IA: usar `PROMPT_FIRMWARE_STYLE_EXPERTS.md` + guías de detalle.

## Excepciones
- Módulos heredados mantienen nombres públicos.  
- Excepciones deben documentarse en el código y en `CHANGELOG_FIRMWARE.md`.

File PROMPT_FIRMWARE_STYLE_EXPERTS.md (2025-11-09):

# Prompt IA - Comentarios y Estilo Firmware FM-320U

## Entradas necesarias
- `FLOWMEET_Embedded_C_Style_Charter.md` (jerarquía y núcleo).
- `STYLE_GUIDE_FIRMWARE_NAMING.md`.
- `STYLE_GUIDE_FIRMWARE_COMMENTS.md`.
- Archivos de ejemplo `fm_style_example.c`, `fm_style_example.h`.
- ARCHIVOS_OBJETIVO a revisar.

## Preparación IA
1. **Síntesis de reglas**: aplicar charter primero, luego naming/comments.
2. **Comprensión**: identificar propósito, dependencias HAL/ThreadX.
3. **Comparar con ejemplos**.

## Análisis
- Riesgos y fallas.
- Concurrencia/RTOS.
- Trazabilidad con requisitos.
- API pública documentada.

## Reescritura
- Mantener funcionalidad.
- Respetar orden includes/bloques.
- Unificar estilo de comentarios.
- Longitud <80 cols.

## Checklist
- Encabezado Doxygen.
- Secciones `// ---`.
- Cierre `/*** END OF FILE ***/`.
- Prefijos correctos.
- Explicación de ISR/colas/mutex.

## Salida requerida
1. Análisis.
2. Cambios propuestos.
3. Archivos actualizados.
4. Notas pendientes.

## Post-proceso
- Revisar diff.
- Compilar rápido.
- Registrar en `CHANGELOG_FIRMWARE.md`.

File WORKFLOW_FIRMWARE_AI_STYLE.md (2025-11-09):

# WORKFLOW_FIRMWARE_AI_STYLE

Guía operativa para usar IA en normalización de estilo FM-320U.

## Archivos a entregar
- `PROMPT_FIRMWARE_STYLE_EXPERTS.md`.
- `FLOWMEET_Embedded_C_Style_Charter.md`.
- `STYLE_GUIDE_FIRMWARE_NAMING.md`.
- `STYLE_GUIDE_FIRMWARE_COMMENTS.md`.
- Archivos objetivo.
- Ejemplos: `fm_style_example.c`, `fm_style_example.h`.

## Procedimiento
1. Revisar `CHANGELOG_FIRMWARE.md` por cambios de estilo.
2. Preparar paquete con los docs arriba.
3. Ejecutar prompt.
4. Validar análisis/diffs (sin cambios funcionales).
5. Registrar en changelog.

## Buenas prácticas
- Si el archivo depende de HAL/ThreadX, indicarlo en el mensaje.
- Procesar archivos uno por uno.
- Usar las guías más recientes.

## Seguimiento
- Registrar excepciones en issues o guías.
- Mantener CI/CD sincronizado para chequeos automáticos.

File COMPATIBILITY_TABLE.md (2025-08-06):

# Tabla de Compatibilidad - Proyecto FMC-320U

Este archivo documenta la compatibilidad entre distintas versiones de firmware, hardware y la aplicación móvil del sistema FMC-320U.

## 📋 Compatibilidad de versiones

| Firmware | Hardware | App | Notas |
|---|---|---|---|
| v01.01.09 | V1R2R1 | | |
| v01.01.10 | V1R1R1 | | No soporta la impresora |
| v01.01.10 | V1R2R1 | | |

##  Consideraciones

- **Firmware puede avanzar más rápido que el hardware**, pero siempre debe mantenerse un registro de compatibilidad.
- **Hardware nuevo puede requerir versiones mínimas de firmware** (por ejemplo, por cambio de microcontrolador).
- La aplicación móvil debe indicar incompatibilidades si detecta hardware o firmware no soportado.

## 🧠 Recomendación
Actualizar esta tabla cada vez que se libere una nueva versión de cualquiera de los tres componentes.

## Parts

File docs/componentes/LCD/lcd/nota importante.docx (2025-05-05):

Hay un error entre en las conexiones del LCD. El comportamiento final es que:

COM 0 de LD se contacta a COM 1 del micro, COM 1 del LCD se con COM 0 del driver.

COM 2 de LD se contacta a COM 3 del micro, COM 3 del LCD se con COM 2 del driver.

El error se puede apreciar comparados las siguientes imágenes:

Captura del Altim Designer, se ve como C1 del LCD conecta a C0 de driver PCF8553.

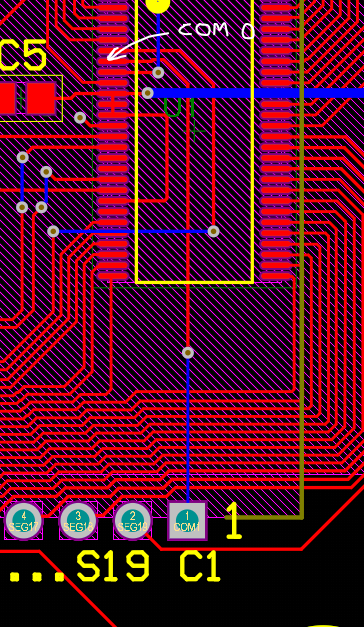
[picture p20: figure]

En las siguientes imágenes se ve la inversión en la conexión, la lograr la siguiente vista en Altium hay que volter la imagen, CRL + F, ya que el LCD no esta del lado componente.

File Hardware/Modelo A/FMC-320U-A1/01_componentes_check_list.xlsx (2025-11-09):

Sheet: CN
Designator | Descripcion | TIPO | PINOUT | Detalles
CN1 | KEYPAD | PCB-WIRE | OK | Se busco que sea compatible con FMC-500
CN2 | DIGITAL | PCB-PCB | OK | Conector de placa 1 a placa 2, señales digitales
CN3 | ANALOGICO | PCB-PCB | OK | Conector de placa 1 a placa 2, señales analgicas
CN4 | STLINKV3 | PCB-WIRE | OK | Model 1.27mm pitch STDC14, concta con el cable plan del STLINK-V3

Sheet: R
Designator | Formato | Potencia | RT | Corriente | Delta TºC

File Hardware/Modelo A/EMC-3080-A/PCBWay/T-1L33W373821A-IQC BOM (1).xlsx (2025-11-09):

T-1L33W373821A-BOM清单
No. Item | 捷创ID | 型号 Mfg Part | 封装 Package/Footprint | 规格参数 Description / Value | 位号 Designator | 单板用量 Qty per board | 总量 Total Qty | 来料数量 Qty Received | 物料备注 Instructions / Notes | 不良原因 Assembly Question | 是否全部空贴 | 是否少料空贴 | 是否按来料贴 | 是否等补料 | 客户回复 Reply from Customer
1 | W228535-001 | CC0805KRX7R8BB104 | 0805 |  | C2 | 1 | 5 | 50
2 | W228535-002 | CC0805KRX5R6BB475 | 0805 |  | C3 | 1 | 5 | 10
3 | W228535-003 | 54101-T0600LF |  |  | CN1,CN2 | 2 | 10 | 0 | 【敏感元器件】：需要掰开使用，请跟工厂确认费用。 | The received male pin header can not match with the holes designed on board dur to the different pitch, please advise for the correct part number. |  |  |  |  | You may use the DZ200R-11-08-39 from LCSC, or any equivalent component you have in stock.
4 | W228535-004 | 54101-T0600LF |  |  | CN3,CN4,CN5 | 3 | 15 | 17 | 【敏感元器件】：需要掰开使用，请跟工厂确认费用。 | For designators CN3,CN4 and CN5, they need 1*2P, while J1 needs 1*3P, we have receicved several 1*2P, one 1*4P and one 1*20P, please advise if you need us to separate the pin header into the required ones or we should change to use another part? |  |  |  |  | You can separate the pin header into the required ones.
5 | W228535-005 | 54101-T0600LF |  |  | J1 | 1 | 5 | 0 | 【敏感元器件】：需要掰开使用，请跟工厂确认费用。
6 | W228535-006 | 17-21SURC/S530-A2/TR8 |  |  | LD1 | 1 | 5 | 20
7 | W228535-007 | 17-21/BHC-XL2M2TY/4T |  |  | LD2 | 1 | 5 | 20 | we will supply is 17-21/BHC-XL2M2TY/4T,OK? please confirm
8 | W228535-008 | DMG3401LSN-7 |  |  | Q1 | 1 | 5 | 10
9 | W228535-009 | RC0805FR-071KL | 0805 |  | R1 | 1 | 5 | 50
10 | W228535-010 | RC0805FR-071ML | 0805 |  | R2 | 1 | 5 | 50
11 | W228535-011 | RC0805FR-072K2L | 0805 |  | R3,R4 | 2 | 10 | 50
12 | W228535-012 | 113990975 |  |  | U1 | 1 | 5 | 5 |  | The received part has extra solder joint that can not match with the board well, please advise if we still can solder it on board? |  |  |  |  | Yes, you can still solder it.
IQC备注

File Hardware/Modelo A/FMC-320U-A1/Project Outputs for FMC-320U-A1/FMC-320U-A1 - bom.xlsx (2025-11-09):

Designator | Quantity | Manufacturer | Manufacturer part number | Main supplier
BH1 | 1 | Myoung | BS-08-B2AA016
C1, C2, C3, C4, C5 | 5 | Yageo | CC0805KRX7R8BB104
C6, C9, C10, C11, C12, C13, C15, C22 | 8 | Yageo | CC0805KRX7R9BB104
C8, C19, C23, C24 | 4 | Yageo | CC0805KKX5R8BB106
C14, C17, C18 | 3 | Yageo | CC0805KKX7R8BB225
C16 | 1 | Yageo | CC0805KKX7R8BB105
C20, C21 | 2 | Yageo | CC0805JRNPO9BN120
CN1 | 1 | XUNPU | PH2.54-07-06PWD
CN2 | 1 | Dealon | DW254R-22-20-85 | LCSC
CN3 | 1 | Dealon | DW254S-22-10-85 | LCSC
CN4 | 1 | Amphenol ICC | 20021511-00014T4LF
ESD1, ESD2, ESD3, ESD4 | 4 | ST | ESDALC6V1W5
J3 | 1 | XUNPU | PH2.54-07-04PWS
L1 | 1 | Murata Electronics | LQM21PN2R2MGHL
LCD1 | 1 | FLOWMEET | FM-160LCD-V2R2R1
LD1 | 1 | Everlight Elec | 17-21SURC/S530-A2/TR8 | LCSC
LD2 | 1 | Everlight Elec | 17-21/BHC-XL2M2TY | LCSC
LD3 | 1 | Everlight Elec | 17-21SYGC/S530-E2/TR8 | LCSC
LSE | 1 | Seiko | SC32S-12.5PF20PPM
Q1 | 1 | Diodes Incorporated | DMG3401LSN-7
R1, R2, R3, R4, R5, R6, R7, R8 | 8 | Yageo | RC0805FR-07100KL
R9 | 1 | Yageo | RC0805FR-071ML
R10, R13, R14, R15, R16, R17, R18, R19 | 8 | Yageo | RC0805FR-0747RL
R11 | 1 | Yageo | RC0805FR-07100RL
R12 | 1 | Yageo | RC0805FR-0710KL
R20, R21, R25, R26 | 4 | Yageo | RC0805FR-071KL
R22, R23, R24 | 3 | Yageo | RC0805FR-072K2L
SW1, SW2, SW3, SW4 | 4 | XKB Connectivity | TC-1102-B-A-B | LCSC, [NoParam]
U1 | 1 | NXP | PCF8553DTT/AY
U2 | 1 | ST | STM32U575VIT6Q

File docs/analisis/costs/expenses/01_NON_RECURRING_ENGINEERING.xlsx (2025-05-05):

FECHA | PROVEEDOR | REFERENCIA | ELEMENTOS | COSTO A$R | COTIZACION | COSTO USD | PRORRATEO | SUB-TOTO USD
2021-06-12 | MERCADO LIBRE |  | ESP32 | 1645 | 100 | 16.45 | 1 | 16.45
2022-07-15 | MERCADO LIBRE |  | ESP32 | 1750 | 101.25 | 17.28 | 1 | 17.28
2021-07-20 | MERCADO LIBRE |  | ESP32 | 4413.99 | 101.5 | 43.49 | 1 | 43.49
2021-10-21 | MERCADO LIBRE |  | ESP32 | 3555.95 | 104.75 | 33.95 | 1 | 33.95
 | MOUSER | Orden de venta N.º: 260479386 | MODULOS ESP-32 | 11887.92 | 118.48 | 100.34 | 1 | 100.34
 | MOUSER | Orden de venta N.º: 260885815 | MODULOS ESP-32 | 10029.9 | 118.48 | 84.65 | 1 | 84.65
2022-07-18 | MOUSER | Orden de venta N.º: 261441392 | NUCLEO-L452RE | 6922.52 | 135.25 | 51.18 | 1 | 51.18
2022-09-10 | MOUSER | Orden de venta N.º: 261441392 | NUCLEO-L496ZG | 8323.42 | 141.38 | 58.87 | 1 | 58.87
2022-09-11 | MERCADO LIBRE | ELECTROCOMPONENTES | MULTIMETRO UNI-T | 48402.68 | 141.38 | 342.36 | 1 | 342.36
2022-09-12 | DRIHM | DRIHM | MULTIMETROS APA | 129505 | 141.38 | 916.01 | 1 | 916.01
2022-10-04 | MOUSER | Orden de venta N.º: 262509584 | STLINK Y TERMINALES | 10254.6 | 148.03 | 69.27 | 1 | 69.27
2022-10-19 | MOUSER | Orden de venta N.º: 262726279 | NUCLEO-L452RE Y I2C A SERIE | 9644.46 | 155.00 | 62.22 | 1 | 62.22
2022-10-27 | MOUSER | Reembolso | NUCLEO-L496ZG | -5323.42 | 155.00 | -34.34 | 1 | -34.34
 |  |  |  |  |  |  |  | 1761.732838

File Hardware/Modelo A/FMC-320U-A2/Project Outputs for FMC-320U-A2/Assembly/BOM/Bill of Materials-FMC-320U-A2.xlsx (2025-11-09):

Comment | Description | Designator | Footprint | LibRef | Quantity
STS40-BD1B-R3 | Board Mount Temperature Sensors Base Accuracy Version, I2C Address 0x45 | B1 | STS40BD1BR3 | STS40-BD1B-R3 | 1
ENERGIZER L91 | 2 x AA through hole economic type | BH1 | BATTERY_HOLDER_2XAA | 2462 | 1
4.7uF | CAP 4.7uF SM0805 X5R 10V YAGEO CC2 | C1, C3, C13, C17, C18, C20, C21 | CAP_SM0805_YAGEOCC2_N | CC0805KRX5R6BB475 | 7
100nF | CAP 100nF SM0805 X7R 25V YAGEO CC2 | C2, C4, C9, C12, C14, C15, C16 | CAP_SM0805_YAGEOCC2_N | CC0805KRX7R8BB104 | 7
33pF | CAP 33pF SM0805 NPO 50V YAGEO CC2 | C5 | CAP_SM0805_YAGEOCC2_N | CC0805JRNPO9BN330 | 1
1uF | CAP 1uF SM0805 X7R 25V YAGEO CC2 | C6 | CAP_SM0805_YAGEOCC2_N | CC0805KKX7R8BB105 | 1
47nF | CAP 47nF SM0805 X7R 25V YAGEO CC2 | C7, C8 | CAP_SM0805_YAGEOCC2_N | CC0805KRX7R8BB473 | 2
DW200R-11-08-43 | 1 x 8 - tru hole 2mm - altura 4.3mm | CN1, CN2 | DW200R-11-08-43 | DW200R-11-08-43 | 2
DZ254R-22-20-63 | 2 x 10 - true hole 2.54mm | CN6 | HEADER PIN 2X10 | DZ254R-22-20-63 | 1
Uar Equivalente | 2 x 5 - true hole 2.54mm | CN8 | HEADER PIN 2X5 MIRROR | DZ254R-22-10-63 | 1
BAV23S | DIODE ARRAY GP 250V 200MA SOT23 | D1, D2, D3, D4, D5, D6 | BAV23S | BAV23S | 6
SMBJ28CA-13-F |  | D7 | SMBJ28CA-13-F | SMBJ28CA-13-F | 1
0ZCJ0005FF2E | PTC RESET FUSE 60V 50MA 1206 | F1 | 0ZCJ0005FF2E | 0ZCJ0005FF2E | 1
 | 1 x 3 - Cuttable - true hole 2.54mm - Pb free | J1 | HEADER PIN 1X3 | 54101-T0600LF-03 | 1
Usar equivalente | 2 x 4 - true hole 2.54mm | J2 | HEADER PIN 2X4 | 54102-T0604LF-JUMPER | 1
Usar Equivalente | 1 x 2 - true hole 2.54mm - Pb free | J3, J4, J5, J6 | HEADER PIN 1X2 | 54101-T0602LF | 4
WJ15EDGVC-3.81-2P | TERM BLOK FEMALE 1X2 3.81MM | P1, P2 | HEADER PLUG 2 | WJ15EDGVC-3.81-2P | 2
WJ15EDGVC-3.81-3P | TERM BLOK FEMALE 1X3 3.81MM | P3, P4 | HEADER PLUG 3 | WJ15EDGVC-3.81-3P | 2
DMG3402 | N-CHANNEL ENHANCEMENT MODE FIELD EFFECT TRANSISTOR 85mΩ @ VGS = 2.5V -> ID 2A V(BR)DDS 30V | Q2 | DMG3402L-7 | DMG3402L-7 | 1
DMG3401 | P-CHANNEL ENHANCEMENT MODE MOSFET RDS(ON) = 85mΩ @ VGS = -2.5V -> ID -2.7A V(BR)DDS 30V | Q3 | DMG3401LSN-7 | DMG3401LSN-7 | 1
10R | RES 10R SM0805 YAGEO RC_L | R1 | RES_SM0805_YAGEORC_N | RC0805FR-0710RL | 1
10K | RES 10K SM0805 YAGEO RC_L | R3, R4, R10, R14, R27 | RES_SM0805_YAGEORC_N | RC0805FR-0710KL | 5
10M | RES 10M SM0805 YAGEO RC_L | R5, R6 | RES_SM0805_YAGEORC_N | RC0805FR-0710ML | 2
1M | RES 1M SM0805 YAGEO RC_L | R7, R8, R13, R15, R28, R31 | RES_SM0805_YAGEORC_N | RC0805FR-071ML | 6
100K | RES 100K SM0805 YAGEO RC_L | R9, R29 | RES_SM0805_YAGEORC_N | RC0805FR-07100KL | 2
220K | RES 220K SM0805 YAGEO RC_L | R11 | RES_SM0805_YAGEORC_N | RC0805FR-07220KL | 1
1K | RES 1K SM0805 YAGEO RC_L | R12, R30 | RES_SM0805_YAGEORC_N | RC0805FR-071KL | 2
47R | RES 47R SM0805 YAGEO RC_L | R26 | RES_SM0805_YAGEORC_N | RC0805FR-0747RL | 1
MCP6541 | IC COMP PP I/O SNGL 1.6V 8SOIC | U1 | MCP6541-E/SN | MCP6541-E/SN | 1

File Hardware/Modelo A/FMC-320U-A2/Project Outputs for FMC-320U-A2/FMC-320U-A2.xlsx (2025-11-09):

Designator | Category | Quantity | Manufacturer | Manufacturer Part Number | Temperature Max | Temperature Min | Value
BH1 | Battery holder | 1 | Keystone | 2468 | - | -
CN6 | Header pin | 1 | DEALON | DZ254R-22-20-63 | - | -
CN8 | Header pin | 1 | DEALON | DZ254R-22-10-63 | - | -
PTH1, PTH2, PTH3, PTH4 | Mounting Hole | 4 |  |  | - | -
P1, P2 | Bornera enchufable | 2 | Ningbo Kangnex Elec | WJ15EDGVC-3.81-2P | 105 | -40
P3, P4, P5 | Bornera enchufable | 3 | Ningbo Kangnex Elec | WJ15EDGVC-3.81-3P | 105 | -40
U2 | Amplificador operacional | 1 | Gainsil | GS8044-SR | 125 | -40
CN1, J3, J4, J5, J6, J7 | Header pin | 6 | Amphenol ICC | 54101-T0602LF | 125 | -65
J2 | Header pin | 1 | Amphenol ICC | 54102-T0604LF | 125 | -65
C2, C4, C9, C10, C12, C13, C14, C15, C16 | Capacitor | 9 | Yageo | CC0805KRX7R8BB104 | 125 | -55 | 100nF
C5 | Capacitor | 1 | Yageo | CC0805JRNPO9BN330 | 125 | -55 | 33pF
C6 | Capacitor | 1 | Yageo | CC0805KKX7R8BB105 | 125 | -55 | 1uF
C7, C8 | Capacitor | 2 | Yageo | CC0805KRX7R8BB473 | 125 | -55 | 47nF
C11 | Capacitor | 1 | Yageo | CC0805KRX7R8BB103 | 125 | -55 | 10nF
D1, D2, D3, D4, D5, D6 | Diodo | 6 | onsemi | BAV23S | 150 | -55
D7 | Diodo | 1 | Diodes Incorporated | SMBJ24CA | 150 | -55 | 24V - 26.7V - 38.9V
Q1, Q3 | Transistor mosfet | 2 | Diodes Incorporated | DMG3401LSN-7 | 150 | -55
Q2 | Transistor mosfet | 1 | Diodes Incorporated | DMG3402L-7 | 150 | -55
J1 |  | 1 | Amphenol ICC | 54101-T06-00 | 155 | -55
R1 | Resistor | 1 | Yageo | RC0805FR-0710RL | 155 | -55 | 10R
R2 | Resistor | 1 | Yageo | RC0805JR-070RL | 155 | -55 | 0
R5, R6, R7, R8, R13, R15, R28, R31 | Resistor | 8 | Yageo | RC0805FR-071ML | 155 | -55 | 1M
R9, R17, R19, R20, R21, R23, R29 | Resistor | 7 | Yageo | RC0805FR-07100KL | 155 | -55 | 100K
R10, R14, R25, R27 | Resistor | 4 | Yageo | RC0805FR-0710KL | 155 | -55 | 10K
R11 | Resistor | 1 | Yageo | RC0805FR-07220KL | 155 | -55 | 220K
R12, R22, R30 | Resistor | 3 | Yageo | RC0805FR-071KL | 155 | -55 | 1K
R16 | Resistor | 1 | Yageo | RC0805FR-07200KL | 155 | -55 | 200k
R18 | Resistor | 1 | Yageo | RT0805FRE072K49L | 155 | -55 | 2.49K
R24 | Resistor | 1 | Yageo | RC0805FR-0782KL | 155 | -55 | 82K
R26 | Resistor | 1 | Yageo | RC0805FR-0747RL | 155 | -55 | 47R
BH2 | Battery holder | 1 | Myoung | BS-2032-8KC | 85 | -25
EMC3080-P | BLE Module | 1 | MXCHIP | EMC3080-P | 85 | -25
F1 | Fusible | 1 | Bel Fuse Inc. | 0ZCJ0005FF2E | 85 | -40
U1 | Amplificador operacional | 1 | Microchip Tech | MCP6541-E/SN | 85 | -40
C1, C3, C17, C18, C20, C21 | Capacitor | 6 | Yageo | CC0805KRX5R6BB475 | 85 | -55 | 4.7uF

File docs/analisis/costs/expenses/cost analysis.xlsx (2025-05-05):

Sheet: READ
EN ESTE ARCHIVO SE INGRESAN TODOS LOS GASTOS RELACIONADOS CON EL PROYECTO

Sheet: FMC-320U-A
LOTE DE 30 PLACAS
Item | Costo BNA
RE FMC-320U-A | $10.00
NRE-BASE | $15.76
PCBWAY | $196.02
LCD | $10.09
 | $221.77 | Costo Total
 | $554.43 | Precio de venta minimo
 | $665.32 | Precio de menta tipico
 | $887.09 | Precio de venta maximo
LOTE DE 30 PLACAS
Item | Costo BNA
RE FMC-320U-A | $10.00
NRE-BASE | $15.76
PCBWAY | $51.20
LCD | $2.45
 | $76.96 | Costo Total
 | $192.39 | Precio de venta minimo
 | $230.87 | Precio de menta tipico
 | $307.83 | Precio de venta maximo

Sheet: PCB
PLACA | LOTE | CANTIDAD | INVOICE | INVOICE UNIDAD | Correction tipo de cambio tarjeta | Liquidacion FedEx - Gasto importacion | Total | DOLAR BNA
#1 | SIMU | 5 | $119.06 | $23.81 | $51.03 | $550.00 | $601.03 | $120.21
#2 | SIMU | 5 | $67.80 | $13.56 | $29.06 | $350.00 | $379.06 | $75.81
 |  |  |  | $37.37 |  |  |  | $196.02 | Total
PLACA | LOTE | CANTIDAD | INVOICE | INVOICE UNIDAD
#1 | SIMU | 5 | $119.06 | $23.81
#2 | SIMU | 5 | $67.80 | $13.56
 |  |  |  | $37.37 | $51.20 | Total

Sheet: RE
Costos de ingenieria recurrentes. Principalmente relacionados con el control de calidad, pre-armado. La intervercion de i+d hasta entregar a produccion. Puede ser diferente en cada placa.

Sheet: NRE-BASE
Costos no recurrentes. Son los cotos asociados al desarrollo. Se prorratean a las cantidad de unidades que se van a construir en el ciclo de vida del proyecto. Este costo se considrea como un costo comun para todos los modelos FMC-320. Luego cada modelo particular del FMC-320 podra tener costos recurrentes asociados
Fecha | Vendedor | Item | Costo | Costo USD BNA | Prorrateado | Column1 | Descripcion
 |  | PC ESCRITORIO | 480 | 480 | $0.24 | 1.52%
 |  | MONITORES | 272 | 272 | $0.14 | 0.86%
 |  | ESP-PROG | $12.00 | $24 | $0.01 | 0.08%
 |  | ESP32 | $100.67 | $201.34 | $0.10 | 0.64%
 |  | Multimetro | $878.00 | $878 | $0.44 | 2.79% | Dos multimetros
 | Mouser | nRF-PPK2 | $90.00 | $180 | $0.09 | 0.57% | Current, Power & Voltage Monitor
 |  | Placa Nucleo | $24.00 | $48 | $0.02 | 0.15% | Placas L4
 | Mouser | 511-NUCLEO-L452RE + Otro | $73.00 | $146 | $0.07 | 0.46% | Dos placas nuclero y conversores SPI USB, son dos compras separadas
 |  | 511-NUCLEO-L496ZG | $40.42 | $80.84 | $0.04 | 0.26% | Cantidad 2
 |  | Discovery Board + Otro | $92.12 | $184.24 | $0.09 | 0.58% | Compras tienda ST
 |  | STLINK V3 + Otro | $46.70 | $100.0714286 | $0.05 | 0.32% | Programador y pines de conexion
 |  | Prototipo | $198.44 | $425.2285714 | $0.21 | 1.35% | PCBWAY 45 placas - Placa #1
 |  | Prototipo | $113.77 | $243.7928571 | $0.12 | 0.77% | PCBWAY 45 placas - Placa #2
 |  | Logistica |  |  | $0.00 | 0.00%
 |  | Desarrollo |  | $29000 | $14.50 | 92.03%
 |  |  |  |  | $0.00
 |  |  |  |  | $0.00
 |  |  | Total | $31511.51286
 |  |  | Prorateo | $2000
 |  |  | Costo/Unidad | $15.76 | Primer Año
 |  |  |  | $17.17 | Segundo Año
 |  |  |  | $18.72
 |  |  |  | $20.40
 |  |  |  | $22.24
 |  |  |  | $24.24

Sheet: LCD
SE PAGO DOS VECES EL HERRAMENTAL, SE LO PROGRATEA A 360 UNIDADES QUE ES LA PRIMERA PRODUCCION
 |  |  |  |  |  | 0.52 | GASTOS A PAGAR EN LA LIQUIDACION DE LA TARJETA
 |  |  |  |  |  | 0.4 | GASTOS DE IMPUESTOS POR EL COURIER
FECHA | GASTO | sub-total | PROGGRATEADO |  | DESCRIPCION | 0.03 | RECARGO ALIBABA
 | $272.00 |  | 360 | $0.76 | PRIMER TOOL FOB + ENVIO
 | $8.16 |  | 360 | $0.02 | RECARGO ALIBABA
 | $144.53 |  | 360 | $0.40 | LIQUIDACION TARJETA
 | $112.06 |  | 360 | $0.31 | FEDEX
 | $272.00 |  | 360 | $0.76 | SEGUNDO TOOL FOB + ENVIO
 | $8.16 |  | 360 | $0.02 | RECARGO ALIBABA
 | $144.53 |  | 360 | $0.40 | LIQUIDACION TARJETA
 | $112.06 |  | 360 | $0.31 | FEDEX
 | 1073.50 |  |  | $2.98 | TOTAL PAGADO HERRAMENTAL
 |  |  |  |  |  | 1476.740069 | IVA PERDICA POR INFLACION
FECHA | GASTO | sub-total | PROGGRATEADO |  | DESCRIPCION | 561.6689751 | IIBB PERDIDA POR INFLACION
2021-08-04 | $630.00 |  | 360 | $1.75 | FOB USD 360 UNIDADES PRODUCCION
 | $18.84 |  | 360 | $0.05 | RECARGO ALIBABA | 2038.409044
 | $334.72 |  | 360 | $0.93 | LIQUIDACION VISA
 | $216.00 |  | 216 | $1.00 | PRIMER ENVIO | 20.47623349
 | $6.48 |  | 216 | $0.03 | RECARGO ALIBABA
 | $114.77 |  | 216 | $0.53 | LIQUIDACION VISA
 | $88.99 |  | 216 | $0.41 | FACTURA DE FEDEX
 | $175.00 |  | 144 | $1.22 | SEGUNDO ENVIO
 | $5.25 |  | 144 | $0.04 | RECARGO ALIBABA
 | $92.99 |  | 144 | $0.65 | IMPUESTOS LIQUIDADOS EN VISA
 | $72.10 |  | 144 | $0.50 | FACTURA DE FEDEX
 | 1755.138587 |  |  | $7.10 | TOTAL PAGAFO 360 LCDS
 |  |  | Total | $10.09 | Primer Año
 |  |  |  | $10.99 | Segundo Año

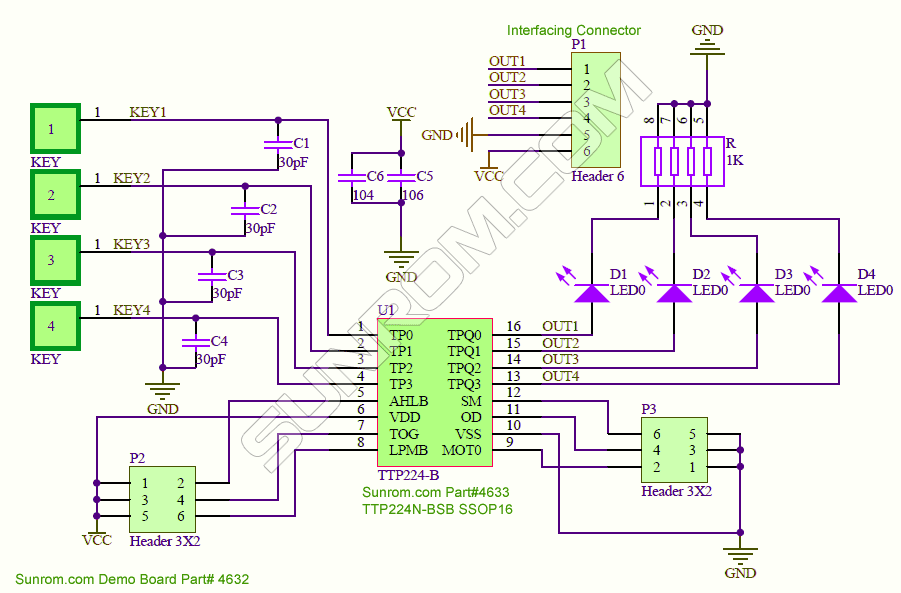
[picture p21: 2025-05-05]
docs/componentes/TTP224C/TTP224C - schmeatic.gif

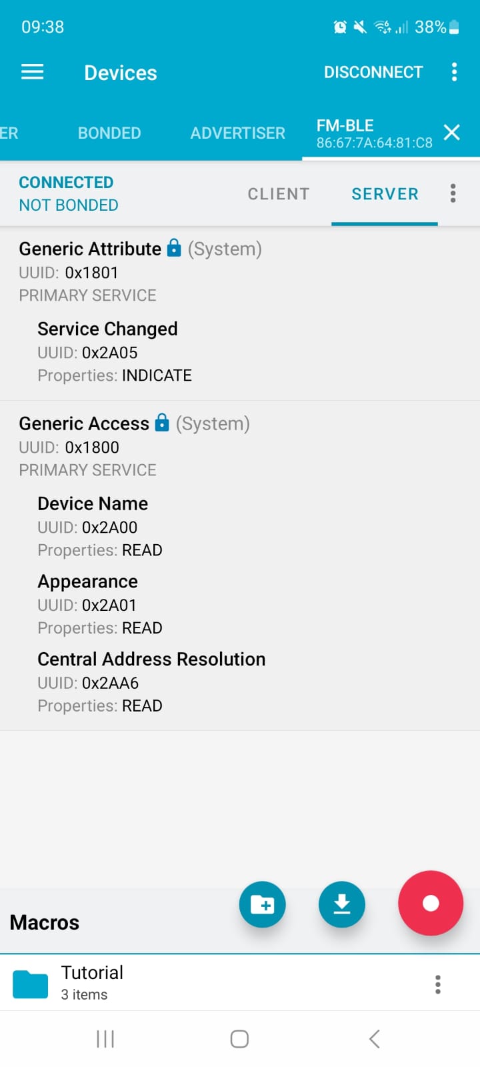
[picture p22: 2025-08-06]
hardware/seleccion_componentes/Impresoras/UUID Server.jpeg

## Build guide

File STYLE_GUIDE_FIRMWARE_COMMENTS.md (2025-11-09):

# STYLE_GUIDE_FIRMWARE_COMMENTS

## Jerarquía
1. `FLOWMEET_Embedded_C_Style_Charter.md`.
2. Este documento.
3. Documentación oficial STM32Cube/HAL/ThreadX.
4. Referencias externas.

## Objetivo
Unificar encabezados, secciones y comentarios.

## Preambulo obligatorio
```c
/**
 * @file nombre_archivo.c
 * @brief Resumen conciso en presente.
 *
 * Contexto: dependencias, restricciones, supuestos.
 */
```

## Secciones estándar
- `// --- Includes ---`
- `// --- Defines ---`
- `// --- Types ---`
- `// --- Globals ---`
- `// --- Static Data ---`
- `// --- Public API ---`
- `// --- Static Functions ---`
- `// --- Interrupts ---`

## Funciones
- Públicas: Doxygen con `@brief`, `@param`, `@return`.
- Internas: `//` breve antes de la definición.
- Inline comments: `//`, no `/* */`.

## Estilo
- Voz activa, español neutro sin tildes.
- Máx 80 columnas.
- ASCII plano.

## Cierre
Todos los archivos terminan con:
```
/*** END OF FILE ***/
```

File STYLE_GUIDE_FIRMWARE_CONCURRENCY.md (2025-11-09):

# STYLE_GUIDE_FIRMWARE_CONCURRENCY

## Propósito
Establecer reglas claras para ISR, hilos y comunicación en ThreadX.

## Reglas
- ISR: no malloc, no bloqueos, deferir trabajo a tareas.
- Sin acceso directo a periféricos compartidos: usar colas/event flags.
- Mutex: sólo en tareas, nunca en ISR.
- Prioridades: documentar en header del módulo.
- Timers RTOS: documentar tick, callback y efectos.
- Globals compartidas: siempre protegidas.

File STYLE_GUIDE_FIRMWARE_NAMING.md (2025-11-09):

# STYLE_GUIDE_FIRMWARE_NAMING

## Jerarquía
1. `FLOWMEET_Embedded_C_Style_Charter.md`.
2. Este documento.
3. `STYLE_GUIDE_FIRMWARE_COMMENTS.md` (formato de archivos).
4. Documentación oficial STM32Cube/HAL/ThreadX.
5. Referencias externas (Barr, MISRA, Google C Style Guide).

## Objetivo
Unificar nombres en firmware FMC-320U.

## Principios
- Mantener prefijos históricos (`FM_`, `FMX_`, `HAL_`, `TX_`).
- Para nuevos módulos: `FM_` (driver) y `FMX_` (aplicación).
- Respetar nombres de HAL/ThreadX.

## Ejemplos
- Archivos: `fm_logger.c`, `fmx_menu.c`.
- Headers: mismo nombre que el `.c`.
- API pública: `FM_LOG_Init()`, `FMX_MenuStart()`.
- Internas estáticas: `UpdateCounter()`.
- Tipos: `fm_log_state_t`, `fmx_menu_context_t`.
- Constantes/macros: `FM_LOG_BUFFER_SIZE`.
- Variables:
  - Global exportada: `FM_LOG_QueueDepth`.
  - Estática: `static uint8_t pulse_flag;`.
  - Local: `sample_total`.
- Banderas: `shutdown_flag`, `enabled_flag`.

## Compatibilidad
- No renombrar callbacks HAL/RTOS (`HAL_GPIO_EXTI_Falling_Callback`).
- Para migración de módulos, usar wrappers.

## Referencias
- STM32Cube AN4998.
- ThreadX User Guide.
- Barr Group Embedded C.
- MISRA C:2012.

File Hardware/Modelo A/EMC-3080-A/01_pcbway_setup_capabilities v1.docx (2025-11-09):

Este documento describe cuales son las capacidades de fabricación de PCBWAY y como se traducen a configuraciones del Altium Designer.

Layers: hasta 10 V -> OK

Material: FR-4 -> OK

PCB máximas dimensiones: 500*1100mm -> OK

PCB toleranciae: Con v-cuting +/- 0.5mm. Con CNC +/- 0,2 mm -> OK

Espesor de placa: 1.6 mm es la más típico, +/- 10%. -> OK

Ancho de pista: ancho el mínimo es de 0.1mm, para fabricación estándar 0.15mm. Al arrancar un diseño establecer 0.2mm como valor mínimo. Se puede reducir solamente si es necesario. -> OK

Separaciones mínimas: el espacio mínimo es de 0.1mm(4 mil), pero para mantener fabricación estándar usar 0.15mm(6 mil), empezar con configuración de espacio de 0.2mm(8 mil), y luego reducir si es necesario. -> OK

Capa de cobre externa o interna: el valor mas usado es el de 1 oz/ ft^2, equivale a un espesor de 35um. -> OK

Tamaños de mecha: de 0.3mm a 6.3mm para lo estándar, tamaños mayores o menores que estos tendrán costo extra. Tamaño final +/- 0.08mm -> OK

Solder mask: el espacio entre mascaras deberá ser mayor a 0.19mm y la expansión entre 0.0508mm y 0.1016mm. https://www.pcbway.com/pcb_prototype/PCB_Solder_mask.html.

Del documento anterior, para Altium Designer se deben ajustar Solder Mask Expansion a 0.102mm y Minimun Solder Mask Silver a 0.051. Para esta configuración si tenemos un error del tipo “Mask Silver”, al correr el Check Rule, hay que expandir el solder mask de los pads para que se solapen.

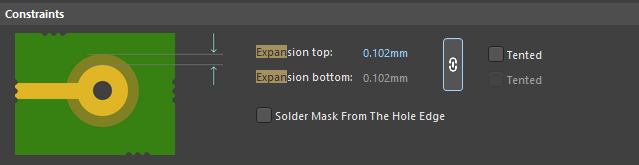
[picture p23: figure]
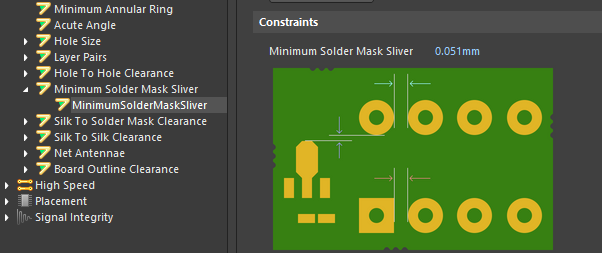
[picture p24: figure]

Board outline: se necesita crear la regla BoardOutlineClearence. Esta verifica que ningún elemento este tan cerca del borde que viole una regla de fabricación. Al crear un cooper pour este no puede llegar al borde de la placa, al crear esta regla a generar los polígonos automáticamente se separan del borde. -> OK

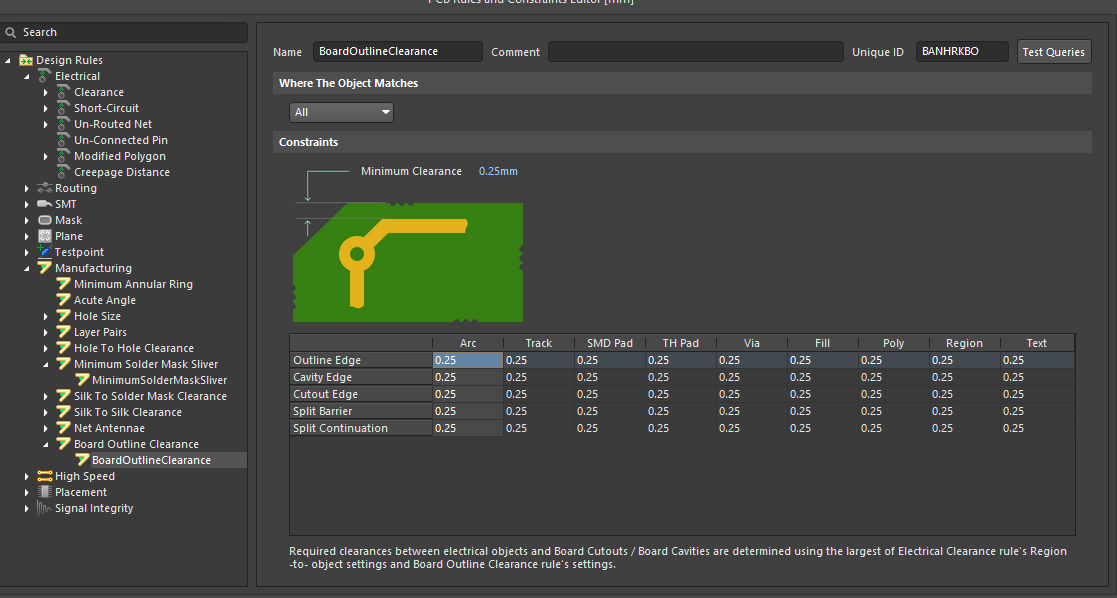
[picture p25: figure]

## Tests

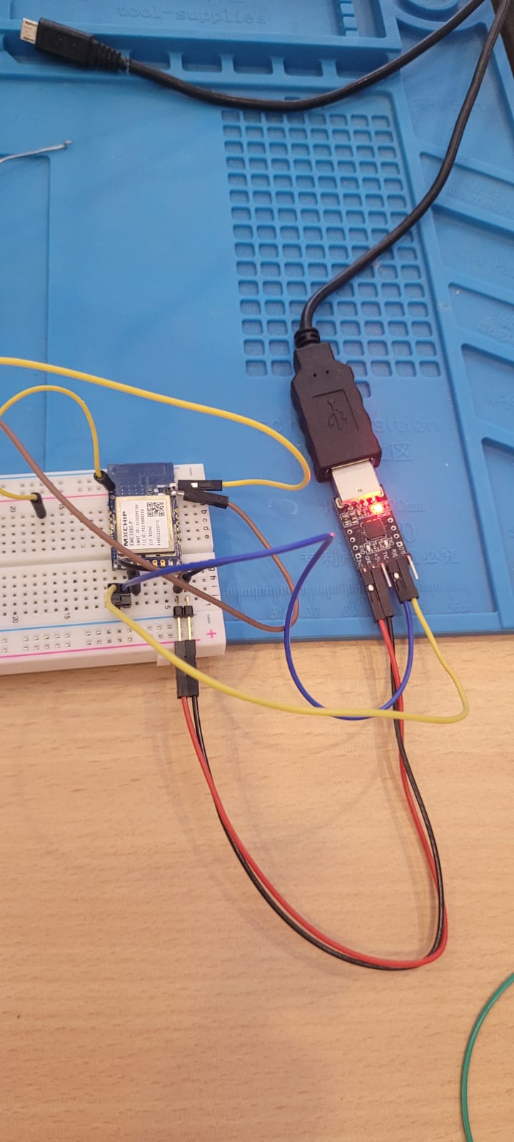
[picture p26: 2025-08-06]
hardware/seleccion_componentes/Impresoras/Experimental.jpeg

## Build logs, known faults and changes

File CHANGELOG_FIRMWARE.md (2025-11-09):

# Firmware change log for the FM-320U computer

## [01.01.011-B0]

### Docs
- Ajusto descripciones del arvhivo 100 - Casos de uso.docx

### Chore

### Added

### Fixed
- Rate no se calculaba correctamete, queda mas simple.
- Intercambio las funciones de boton arriba y abajo en el menu TTL-RATE, tiene mas logica.

### Refactor

### Removed

### Power Consumption

### Completed Tests
TESTEO 0x2FB396C8
TESTEO 0x2FB39787
TESTEO 0x2FB397FE
TESTEO 0x2FB398FC
TESTEO 0x2FB40A04

---------------------------------------------------------------------------------------------------

## [01.01.010-B0+2] Beta
(I keep these changes so I can check out other versions; I want to test printing previous versions.)

### Docs
- Updated the administration folder documents.
- Reorganized the style guides in `STYLE_GUIDE_FIRMWARE_COMMENTS.md`, `STYLE_GUIDE_FIRMWARE_NAMING.md`, documented the flow in `WORKFLOW_FIRMWARE_AI_STYLE.md`, prepared `PROMPT_FIRMWARE_STYLE_EXPERTS.md`, and added examples `fm_style_example.c/.h` for use with AI and humans.

### Chore

### Added
- Added a Bluetooth screen for data download; it is not functional yet.

### Fixed
- Changed the ThreadX timer type used to debounce external buttons.

### Refactor
- Moved UART3 from ISR-based handling to DMA.
- Removed the use of multiple sleep times to improve power consumption; a cleaner technique will be used later.
- Created the `fm_usart.c` module to improve code clarity in `fm_mxc`.

### Removed

### Power Consumption
60 uA consumption, conditions:
- Consumo medio de un minuto, alimentado por el PPK2, modo "source meter" a 3V
- ST-LINK desconectado conectado
- Activity blue LED disabled.
- Pickups conectado
    - Si inyecto 100hz + 10uA -> 70uA
    - Si desconecto el pickup -2uA -> 58uA

### Completed Tests
TEST 0x2FB396C8
TEST 0x2FB39787
TEST 0x2FB397FE
TEST 0x2FB397FE
TEST 0x2FB398FC

---------------------------------------------------------------------------------------------------

## [01.01.009] 2025-06-07

### Notes

### Added

### Fixed
- Decimal point was not being cleared.

### Changed

### Removed

### Power Consumption

### Completed Tests

---------------------------------------------------------------------------------------------------

## [01.01.009-B3] 2025-05-27

### Notes

### Added

### Fixed
- Did not allow the factor to be set to its minimum value.

### Changed

### Removed

### Power Consumption

### Completed Tests

---------------------------------------------------------------------------------------------------

## [01.01.009-B2] 2025-05-27

### Notes

### Added
- Production documents folder.

### Fixed
- Fixed a screen change error when entering the setup menu.

### Changed
- Scheduled a 200 ms refresh if a character configured to blink is currently off.
- Changed the RTC read order to call `HAL_RTC_GetTime` before the date; this appears to solve the problem when editing the computer date and time.
- Changed how the '.' segment is processed on the 8-segment characters.

### Removed
- Removed the "how to use CHANGELOG_RULES.md" file because the information was duplicated here.

### Power Consumption

### Completed Tests

---------------------------------------------------------------------------------------------------

## [01.01.009-B0] 2025-05-11

### Notes
- Created a new repository; the project starts here from version 01.01.009.
- A naming convention was used to allow multiple CHANGELOG_XYZ.md files.
- Improved the wording of files related to Git Flow.

### Added
- Project initialization.

### Fixed
- Fixed the RTC write issue caused by not zeroing these structures: `RTC_TimeTypeDef time = {0};` and `RTC_DateTypeDef date = {0};`.

### Changed
- Changed the version presentation to 01.01.009-B0.
- Added the tag folder in administration.
- Integrated how the idle time is computed; it is now controlled from `void ThreadEntryMain(ULONG thread_input)`.
- Modified `CONTRIBUTING.md`.

### Removed
- Removed unrelated documents from the administration folder.

### Power Consumption
76 uA consumption, conditions:
- One-minute average measured with the PPK2.
- ST-LINK 3.0 V.
- With ST-LINK connected.
- Activity blue LED disabled.
- Connected to a signal generator through two pickups in series at 100 Hz.
43 uA consumption, conditions:
- One-minute average measured with the PPK2.
- ST-LINK 3.0 V.
- With ST-LINK connected.
- Activity blue LED disabled.
- Without pickups connected.

### Completed Tests
0x2FB396C8 - OK
0x2FB39787 - OK
0x2FB397FE - OK
0x2FB398FC - OK
0x2FB40A04 - OK

---------------------------------------------------------------------------------------------------

## [UNVERSIONEDED]

### Chore
- Translated comments in `fmx.c` and `fmx.h` to English.

### Added

### Fixed

### Refactor

### Removed

### Power Consumption

### Completed Tests

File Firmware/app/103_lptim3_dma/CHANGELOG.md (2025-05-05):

# CHANGELOG

Este archivo documenta los cambios relevantes en el proyecto FMC-320U, versión por versión.

## Convención de símbolos de cambio 
Leer CONTRIBUTING.md antes de hacer cambios al codigo.

## onvención para el control de versiones
Leer CONTRIBUTING.md antes de hacer usar el repositorio, crear brances, tags, hacer commits, etc.

---

## Infrastructura - 20-04-25
Varias modificaciones en la infractructura
(i) Empiezo a usar CHANGELOG.md
(i) Agrego READ.md a proyecto 100_main

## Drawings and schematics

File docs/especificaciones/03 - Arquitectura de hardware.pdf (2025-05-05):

# ESTE ARCHIVO TIENE COMO FIN ÚLTIMO EL MOSTRAR LA ORGANIZACIÓN DEL HARDWARE

DE FORMA GRÁFICA A NIVEL SUPERFICIAL.

# ESTO TIENE EN CUENTA LA DISTRIBUCIÓN DE LOS PERIFÉRICOS EN CADA UNA DE LAS

PLACAS Y LA CONEXIÓN INTERPLACA.

# SE PROFUNDIZA TAMBIÉN EN EL MISMO LAS FUNCIONALIDADES DE COMPONENTES MULTIFUNCIÓN, COMO POR EJEMPLO

MICROCONTROLADORES.

TOUCHPADS | | TECLADO MECÁNICO | | PANTALLA LCD | BACKLIGHT

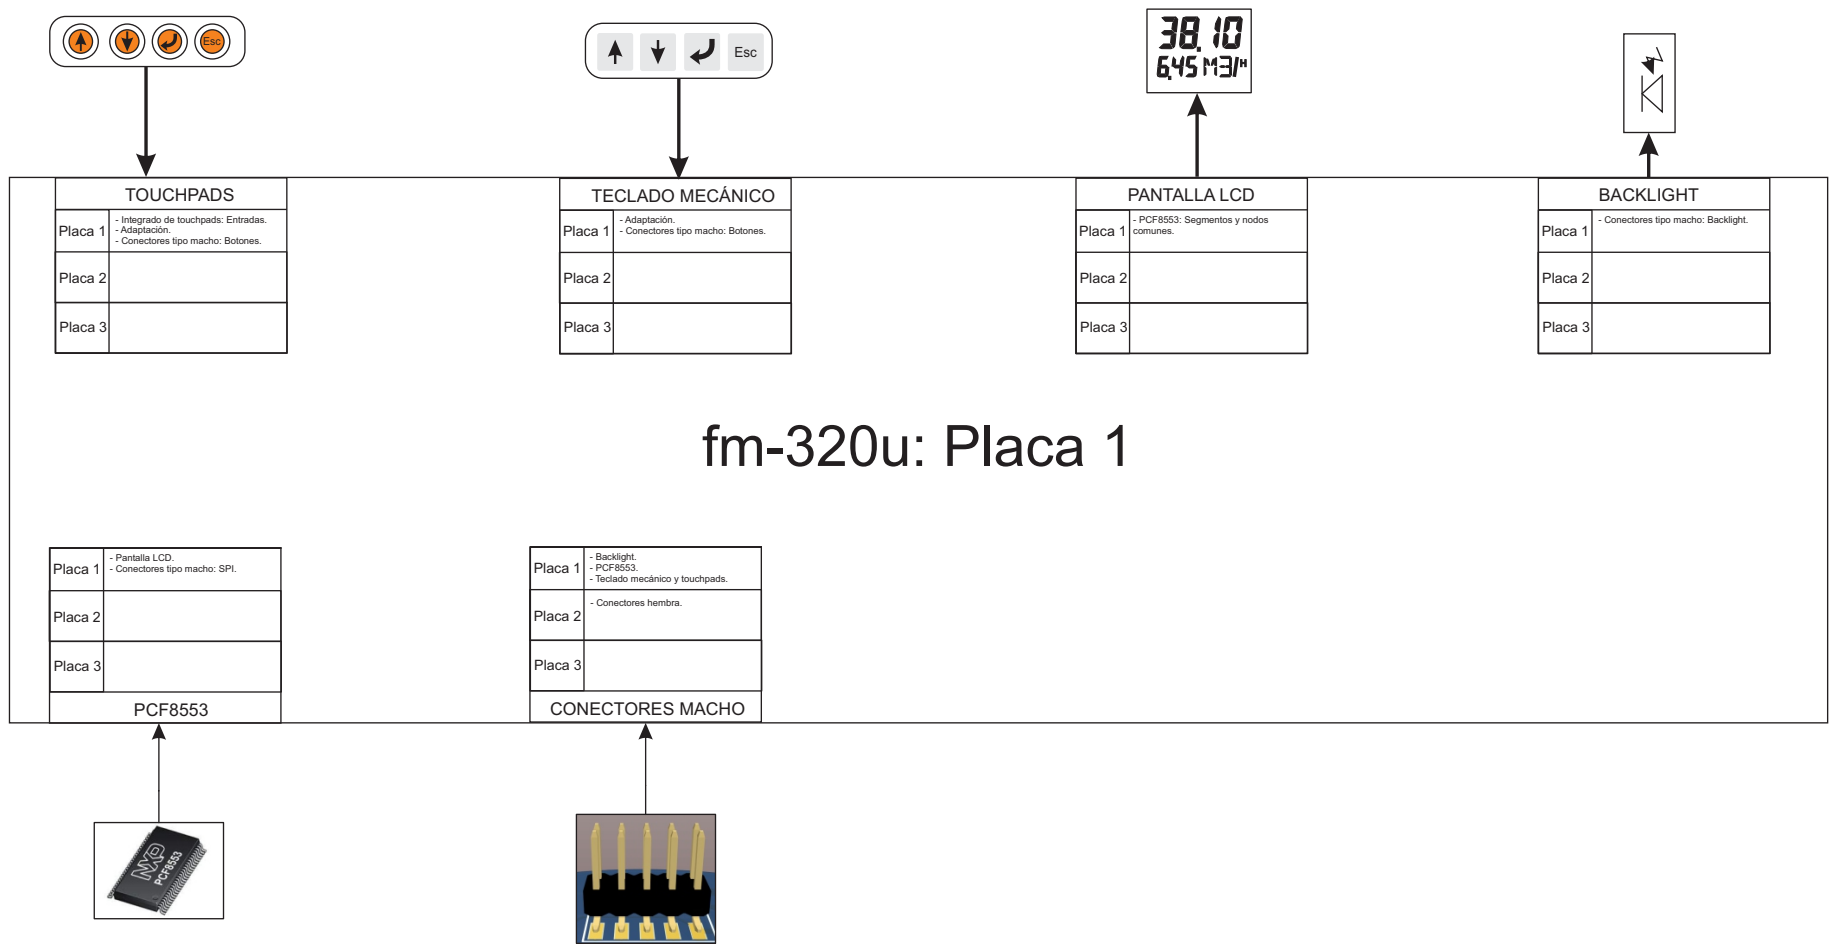
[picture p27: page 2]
fm-320u: Placa 1; Esc; Placa 2; Placa 3; Placa 1; PCF8553; - Backlight. - PCF8553. - Teclado mecánico y touchpads.; CONECTORES MACHO; - Conectores hembra.

Placa 1 | - Integrado de touchpads: Entradas. - Adaptación. - Conectores tipo macho: Botones. | | Placa 1 | - Adaptación. - Conectores tipo macho: Botones. | Placa 1 | - PCF8553: Segmentos y nodos comunes. | Placa 1 | - Conectores tipo macho: Backlight.

- Pantalla LCD.
- Conectores tipo macho: SPI.

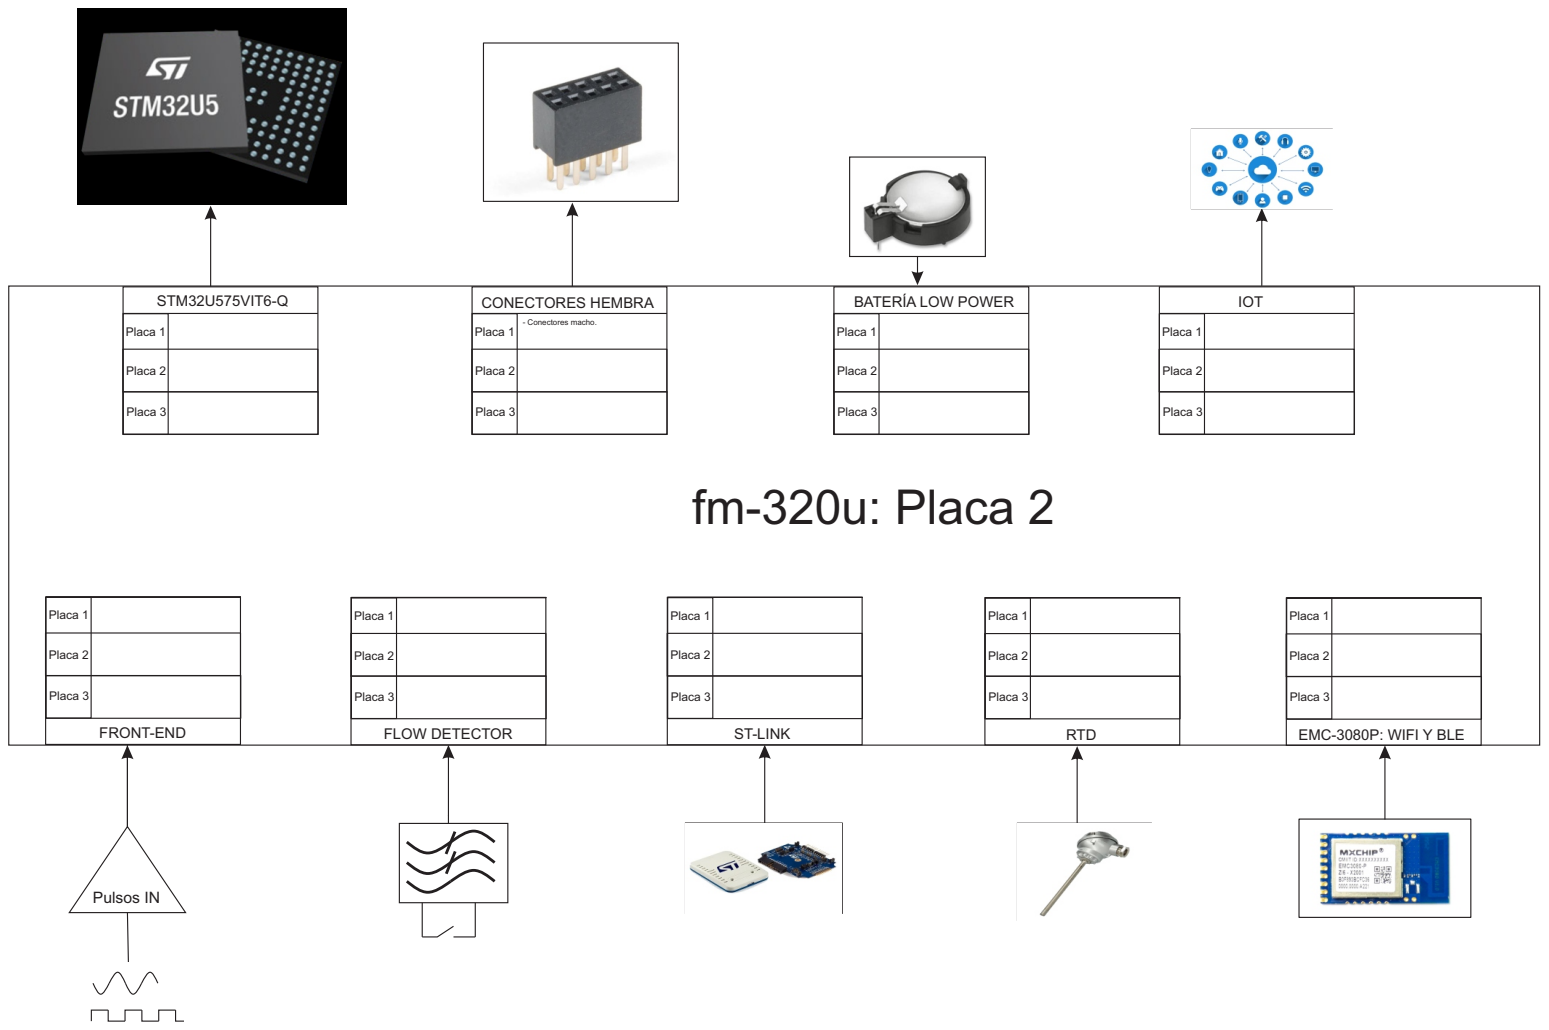
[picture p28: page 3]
fm-320u: Placa 2; Pulsos IN; Placa 1; Placa 2; Placa 3; FRONT-END; ST-LINK; FLOW DETECTOR; RTD

STM32U575VIT6-Q | CONECTORES HEMBRA | | BATERÍA LOW POWER | | IOT

Placa 1 | | Placa 1 | - Conectores macho. | | Placa 1 | | Placa 1

EMC-3080P: WIFI Y BLE

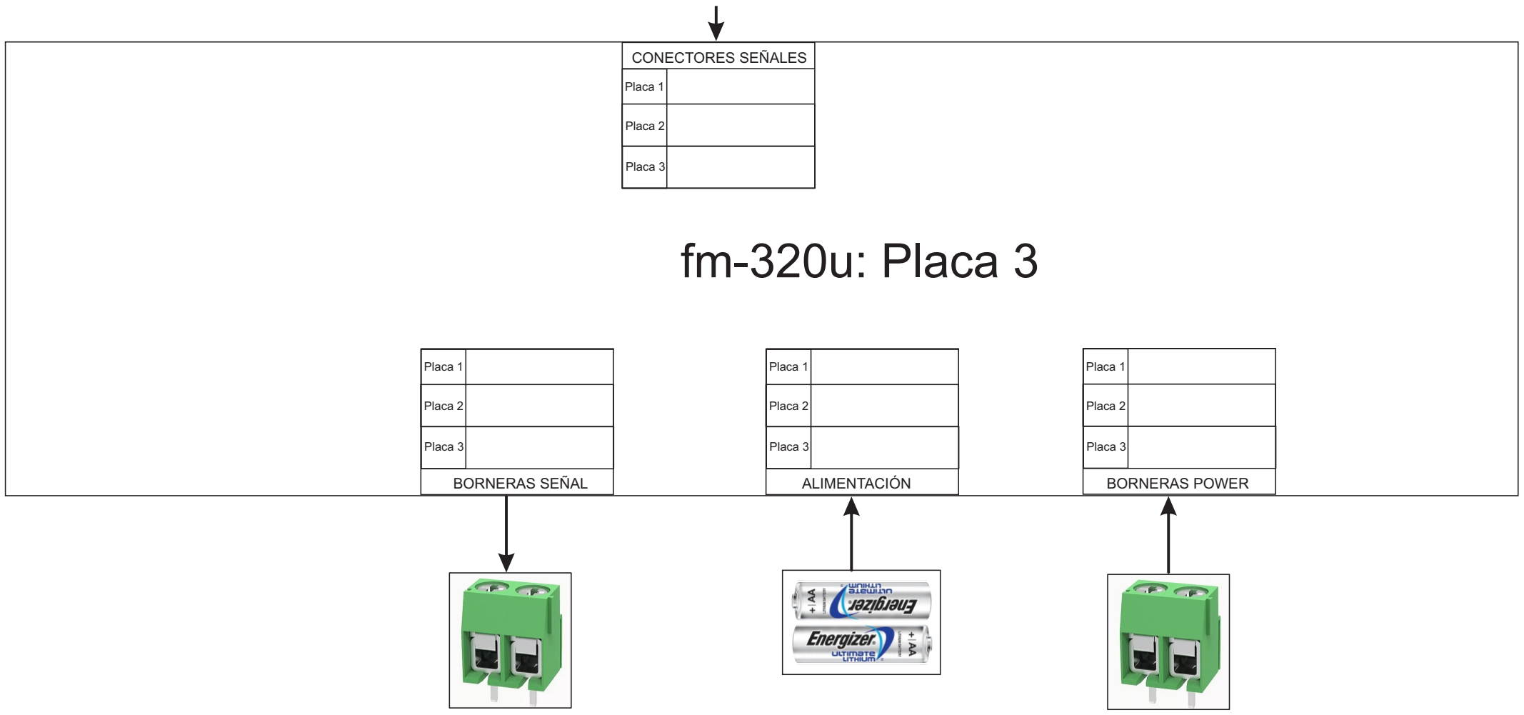
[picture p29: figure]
CONECTORES SEÑALES fm-320u: Placa 3; Placa 1; Placa 2; Placa 3; BORNERAS SEÑAL; ALIMENTACIÓN; BORNERAS POWER

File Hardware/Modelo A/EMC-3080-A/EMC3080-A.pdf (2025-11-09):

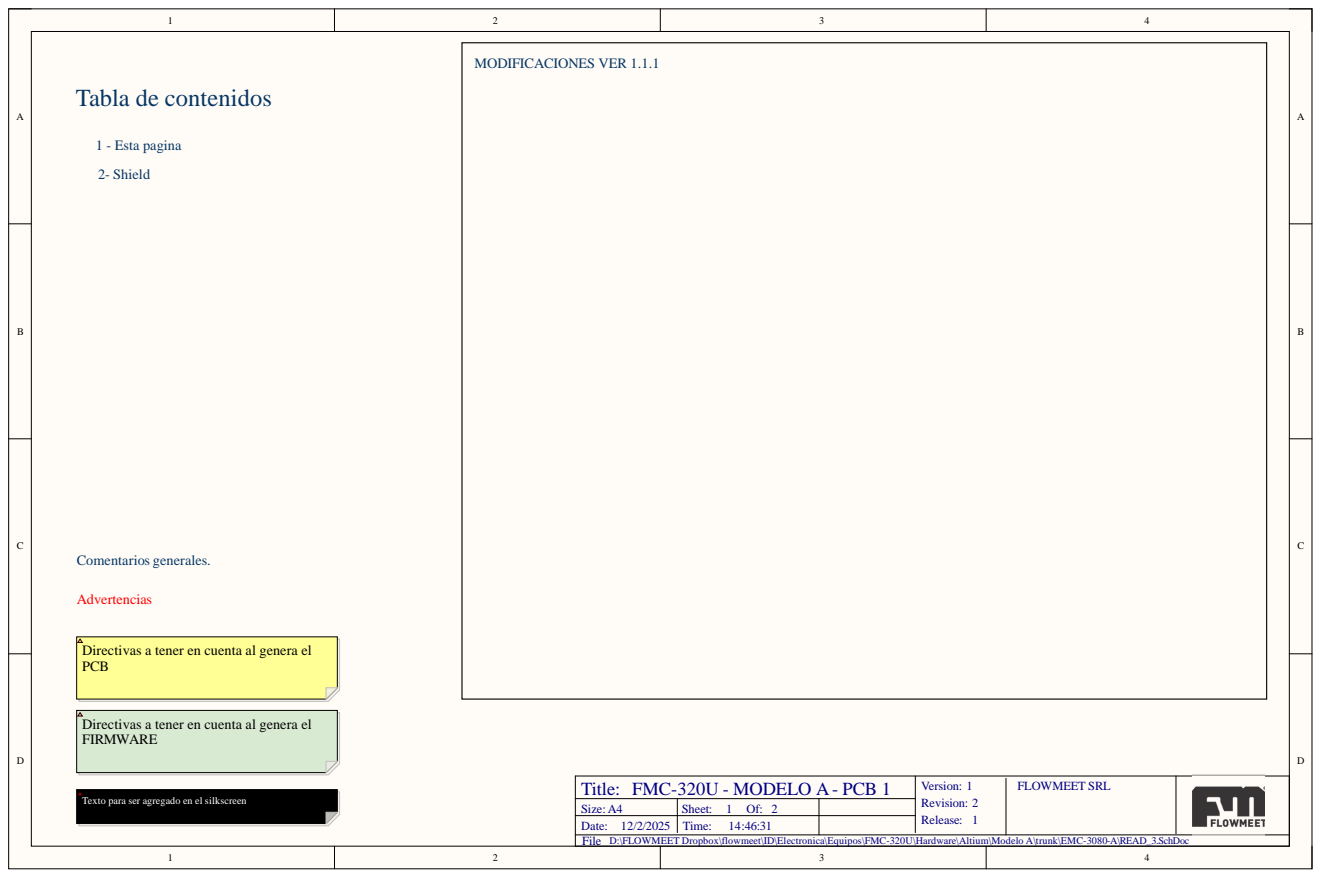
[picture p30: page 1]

Directivas a tener en cuenta al genera el
PCB

FIRMWARE

Title: FMC-320U - MODELO A - PCB 1 | Version: 1 Revision: 2 Release: 1 | FLOWMEET SRL

Texto para ser agregado en el silkscreen

Size: A4 | Sheet: 1 Of: 2
Date: 12/2/2025 | Time: 14:46:31

File
D:\FLOWMEET Dropbox\flowmeet\ID\Electronica\Equipos\FMC-320U\Hardware\Altium\Modelo A\trunk\EMC-3080-A\READ_3.SchDoc

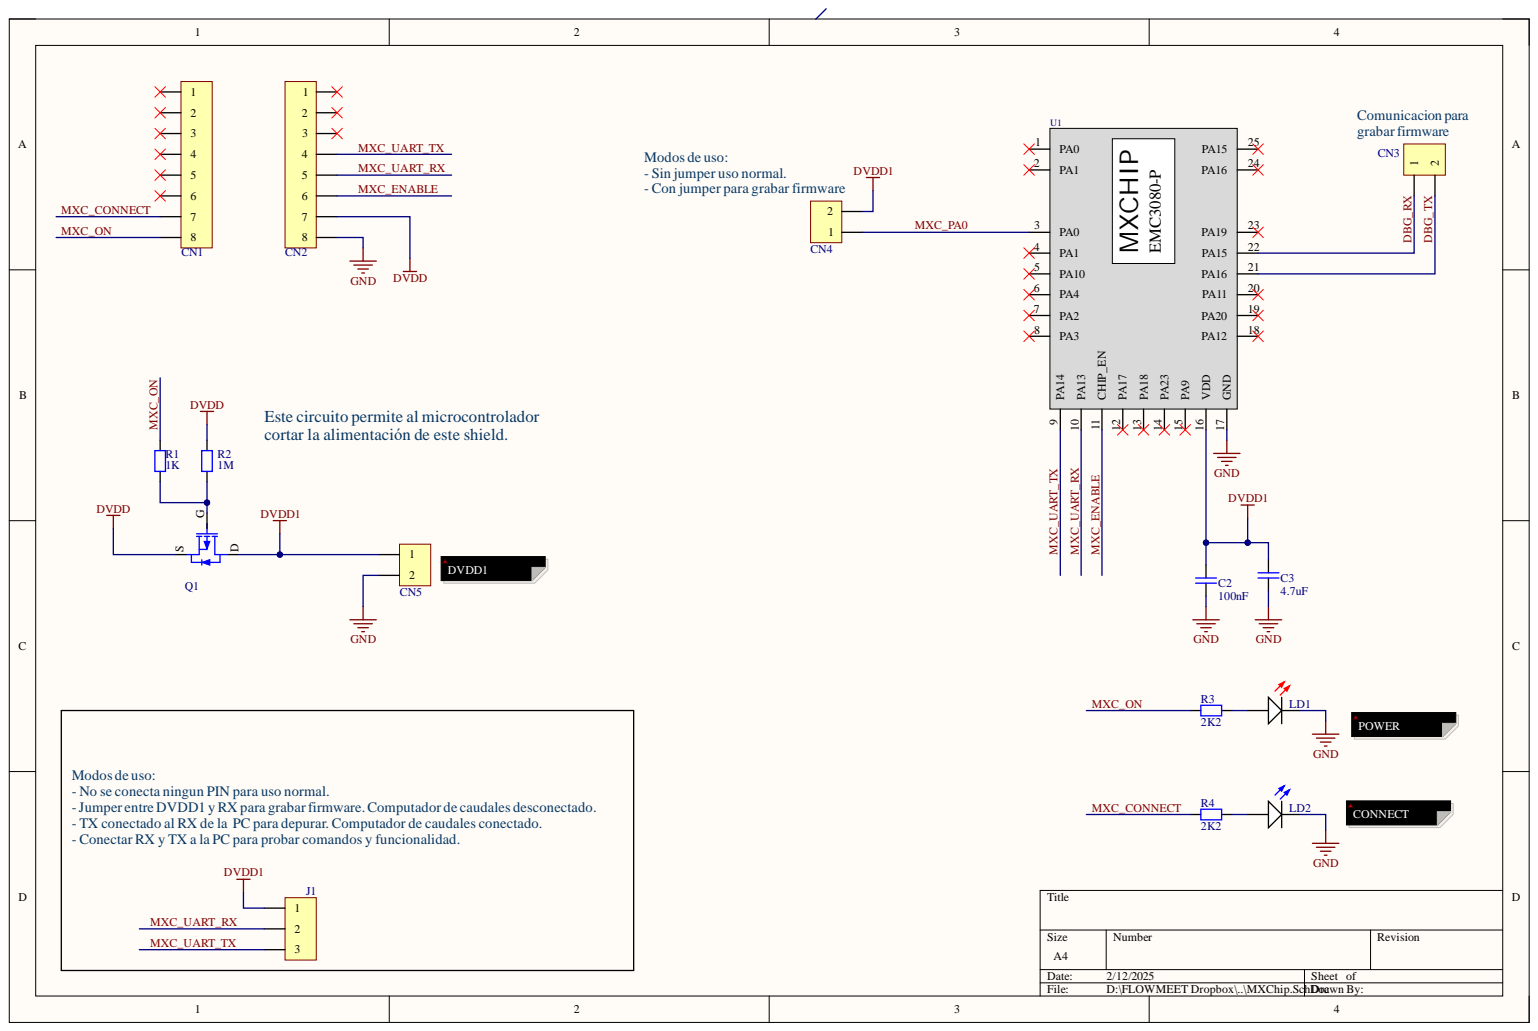
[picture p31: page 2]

Modos de uso:
- Sin jumper uso normal.
- Con jumper para grabar firmware

Este circuito permite al microcontrolador
cortar la alimentación de este shield.

- No se conecta ningun PIN para uso normal.
- Jumper entre DVDD1 yRX para grabar firmware. Computador de caudales desconectado.
- TX conectado al RX de la PC para depurar. Computador de caudales conectado.
- Conectar RX y TX a la PC para probar comandos y funcionalidad.

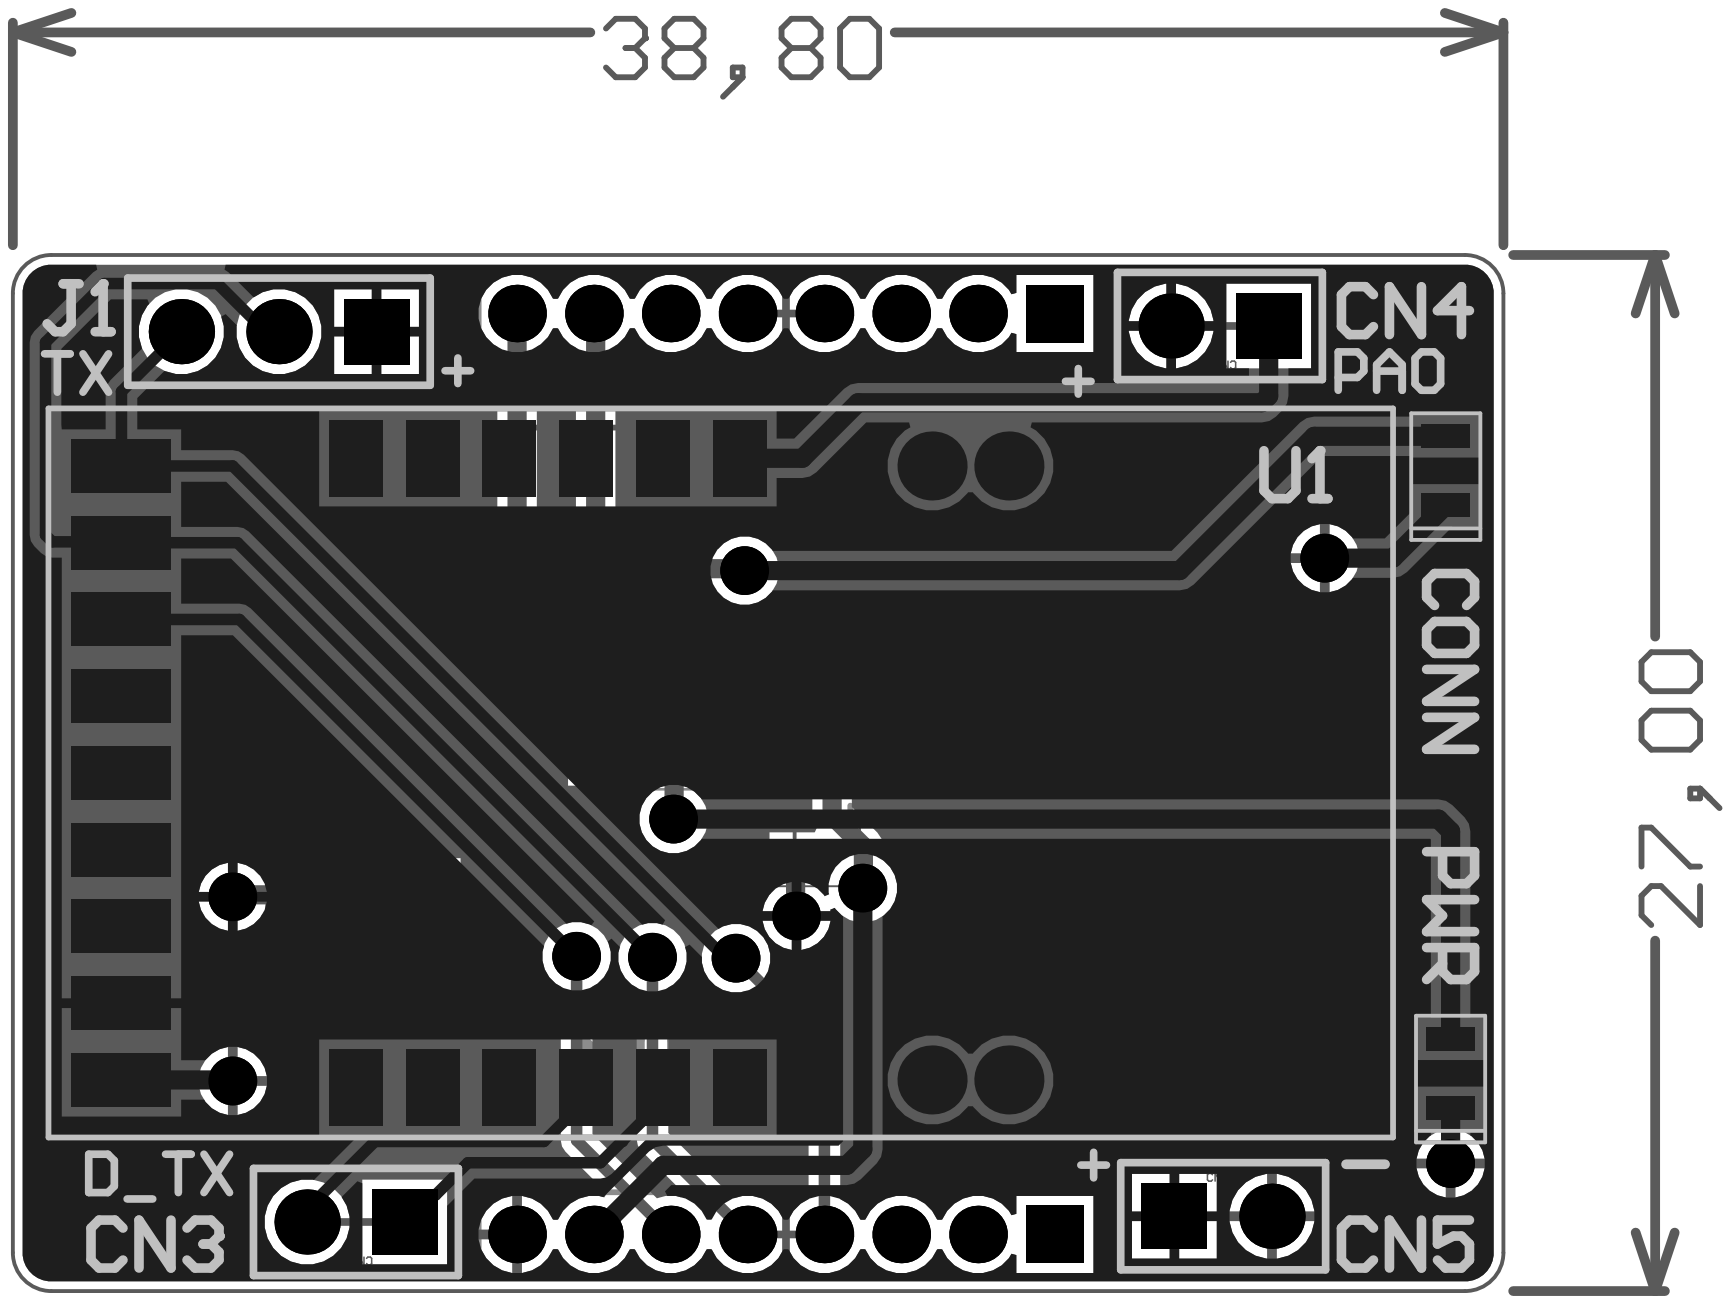
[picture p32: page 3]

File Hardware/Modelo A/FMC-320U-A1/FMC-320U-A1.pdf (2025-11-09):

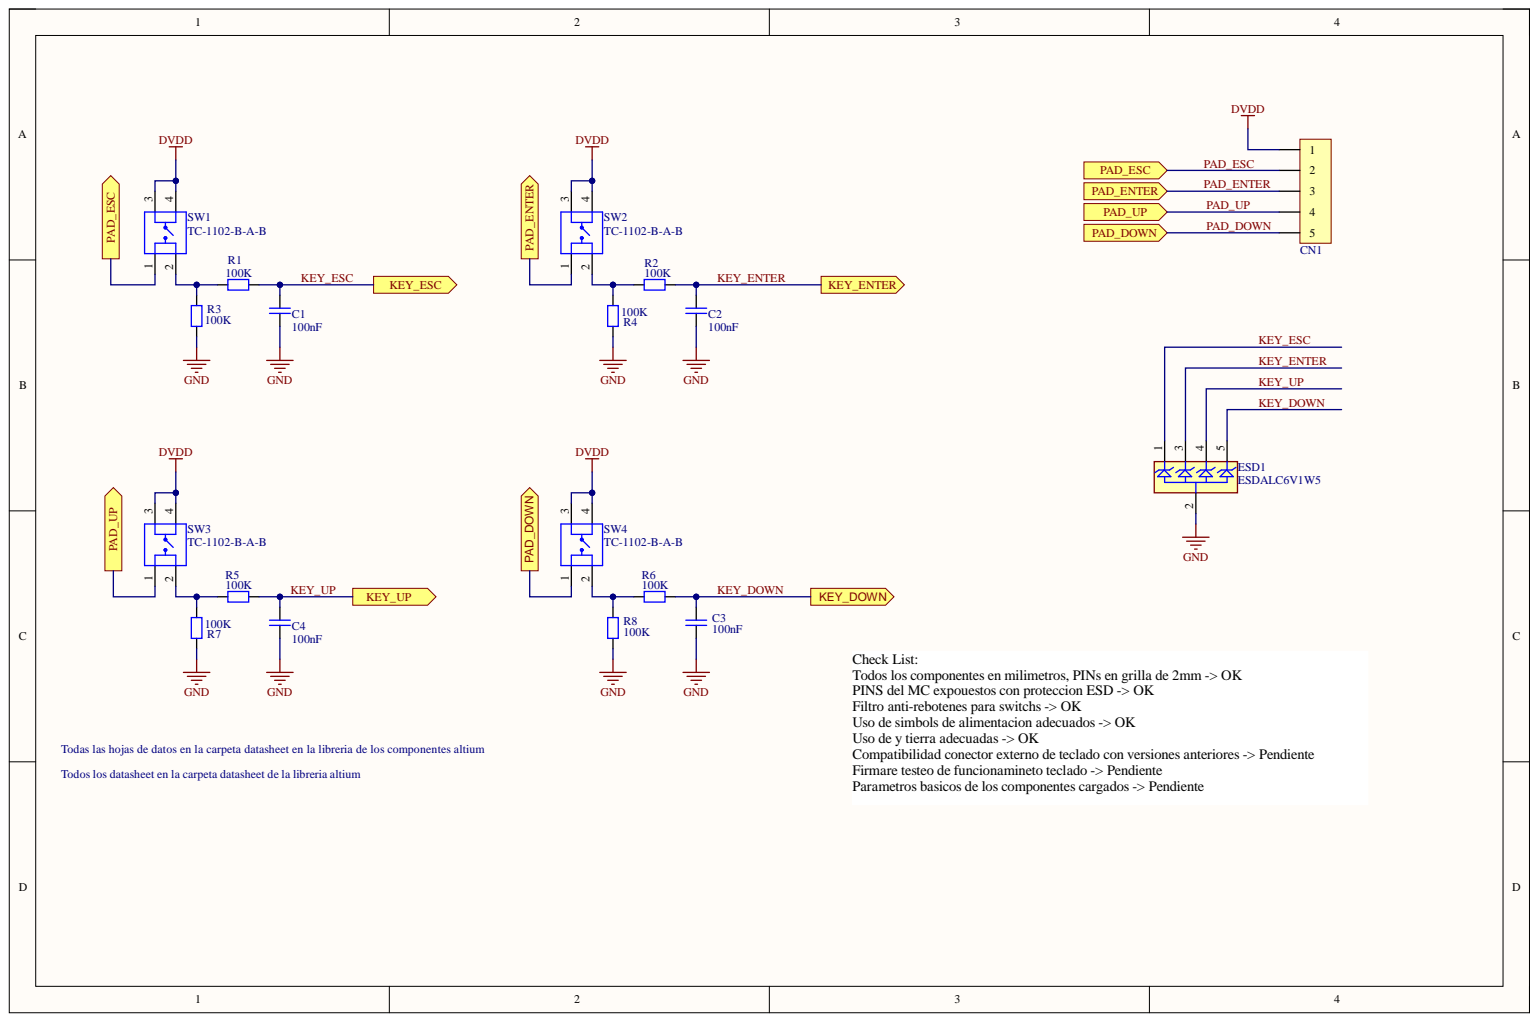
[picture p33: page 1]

s en la carpeta datas

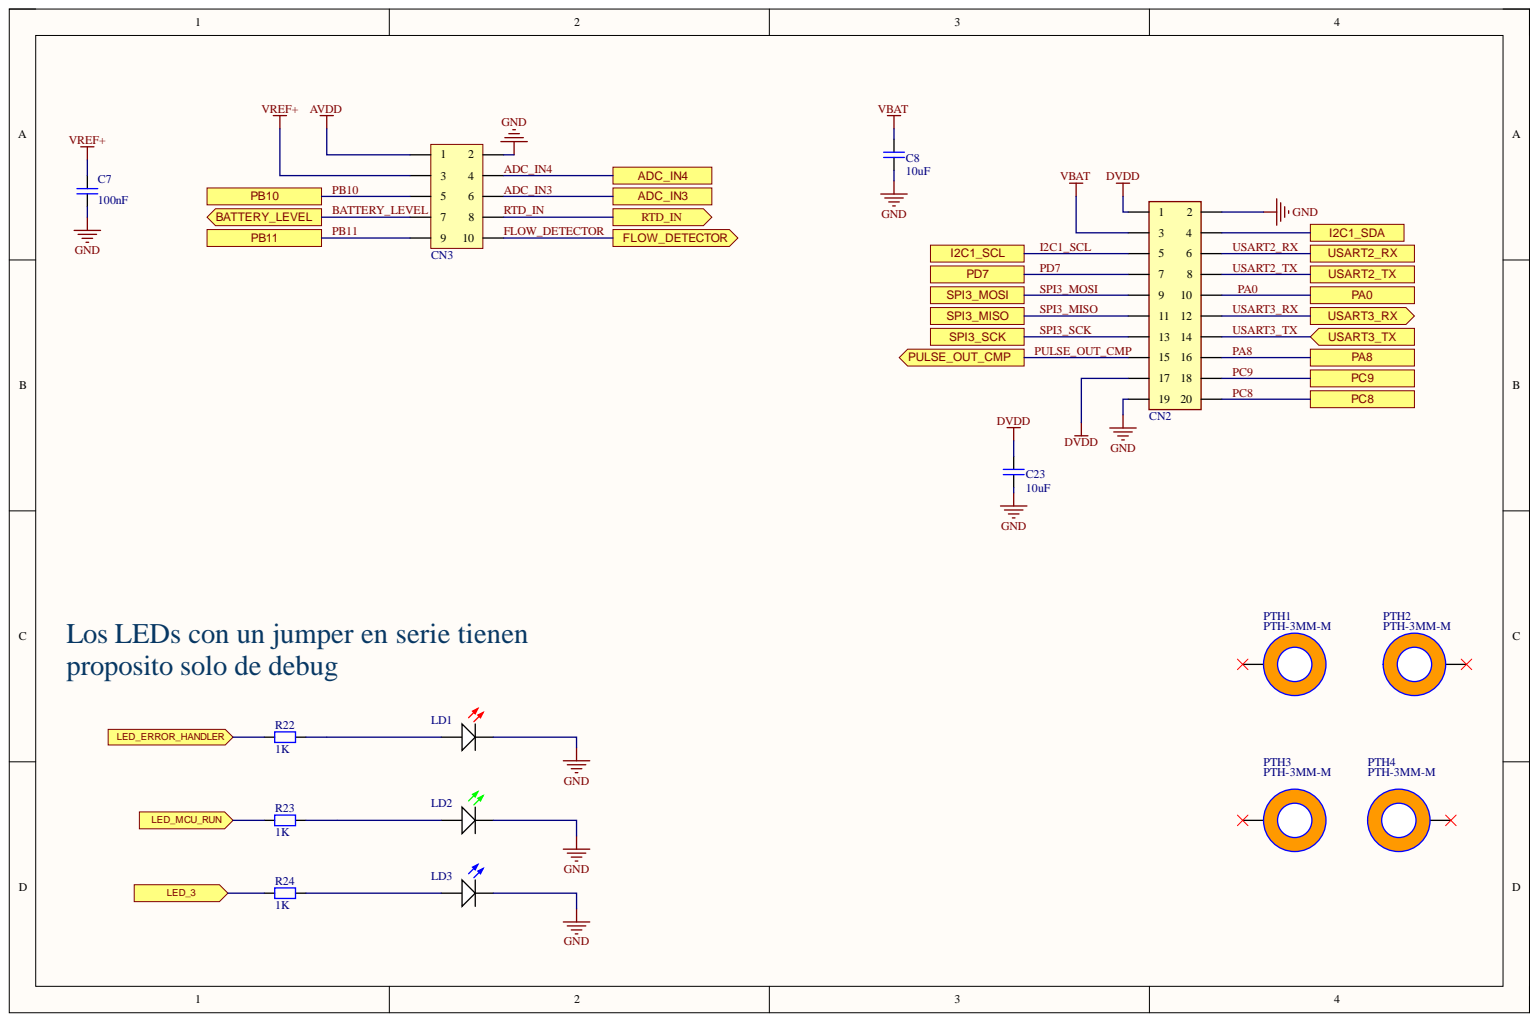
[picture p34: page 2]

Los LEDs con un jumper en serie tienen
proposito solo de debug

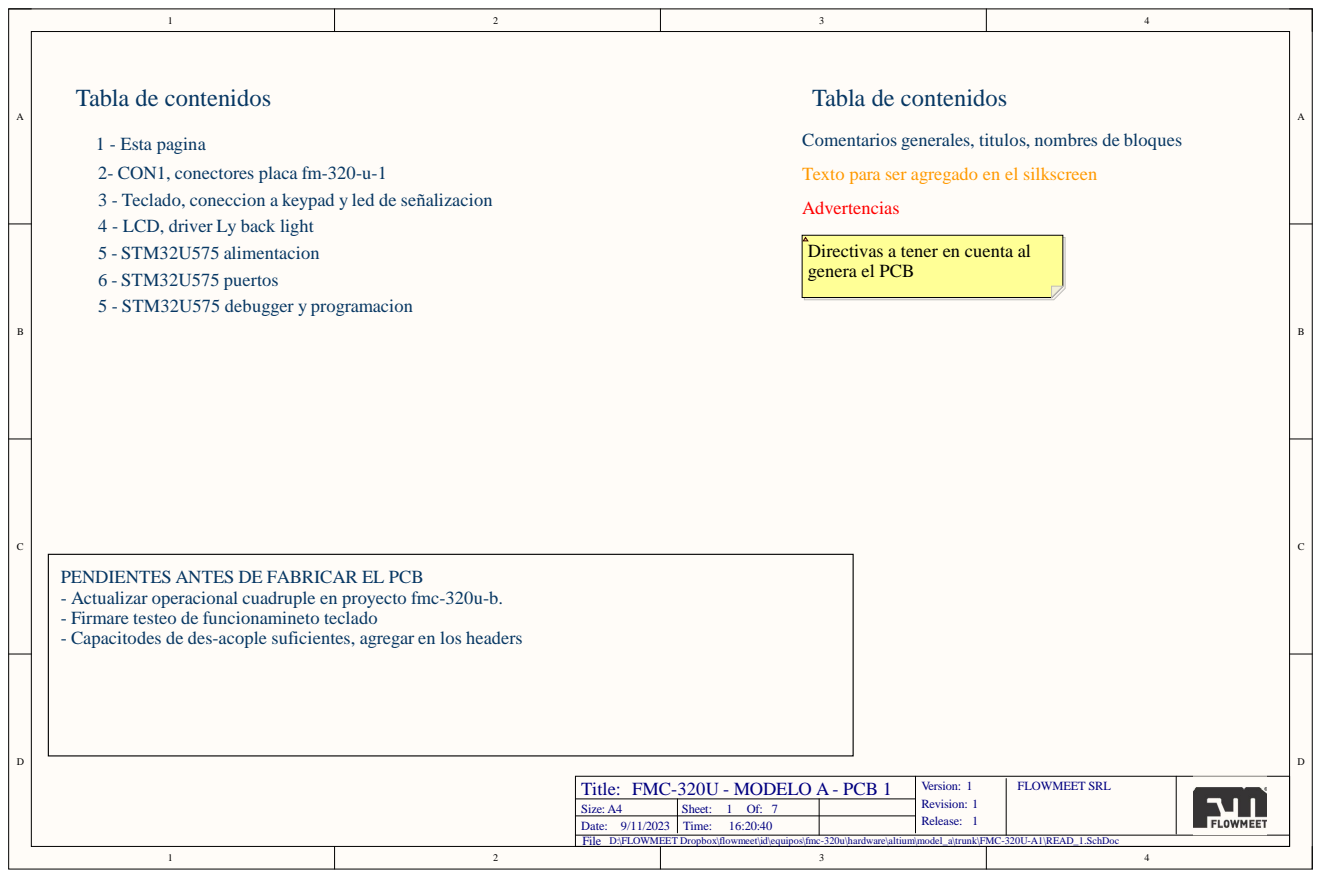
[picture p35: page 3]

1 - Esta pagina
2- CON1, conectores placa fm-320-u-1
3 - Teclado, coneccion a keypad y led de señalizacion
4 - LCD, driver Ly back light
5 - STM32U575 alimentacion
6 - STM32U575 puertos
5 - STM32U575 debugger y programacion

Comentarios generales, titulos, nombres de bloques

Texto para ser agregado en el silkscreen

Directivas a tener en cuenta al
genera el PCB

PENDIENTES ANTES DE FABRICAR EL PCB
- Actualizar operacional cuadruple en proyecto fmc-320u-b.
- Firmare testeo de funcionamineto teclado
- Capacitodes de des-acople suficientes, agregar en los headers

Title: FMC-320U - MODELO A - PCB 1 | Version: 1 Revision: 1 Release: 1 | FLOWMEET SRL

Size: A4 | Sheet: 1 Of: 7
Date: 9/11/2023 | Time: 16:20:40

File
D:\FLOWMEET Dropbox\flowmeet\id\equipos\fmc-320u\hardware\altium\model_a\trunk\FMC-320U-A1\READ_1.SchDoc

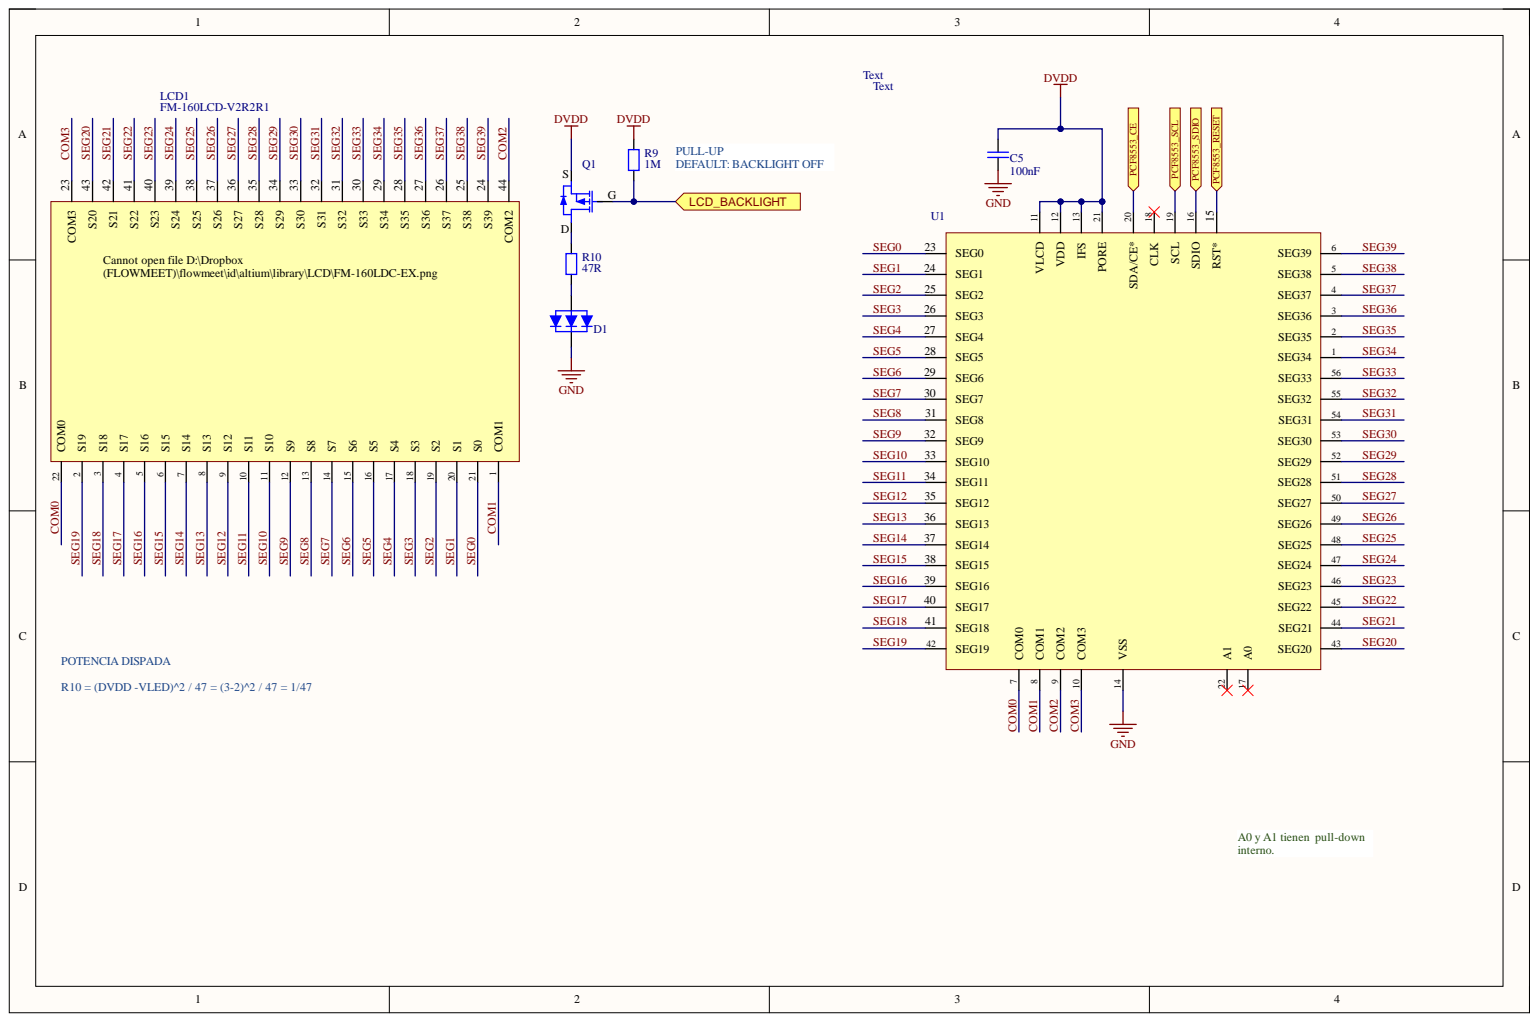
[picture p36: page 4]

Cannot open file D:\Dropbox
(FLOWMEET)\flowmeet\id\altium\library\LCD\FM-160LDC-EX.png

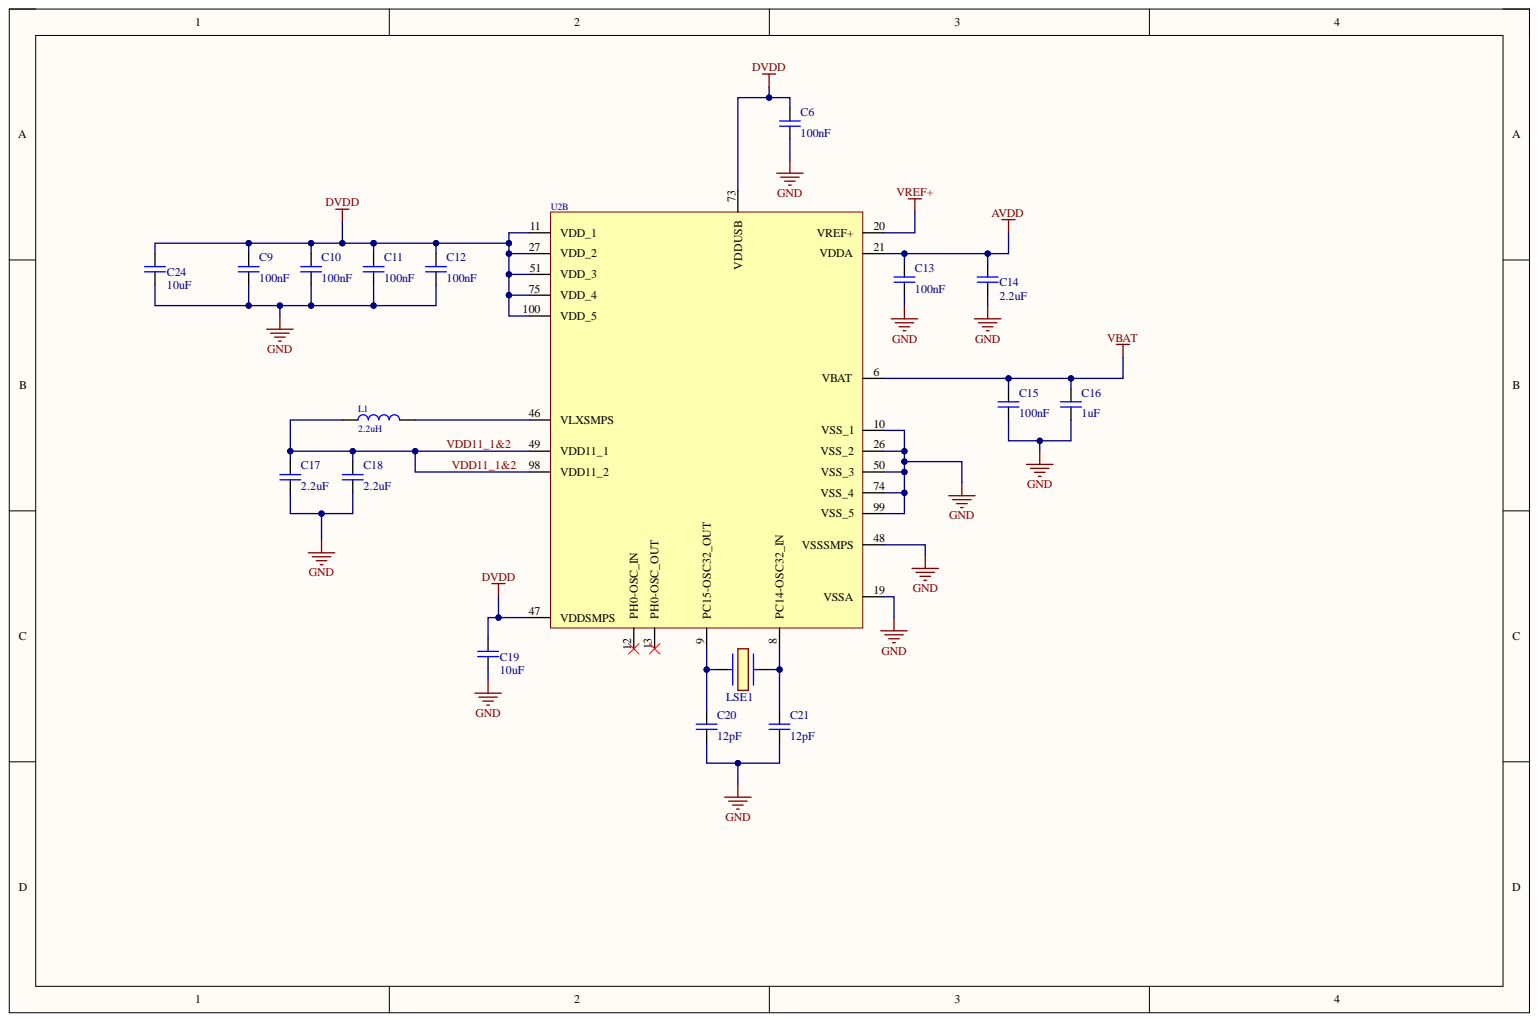
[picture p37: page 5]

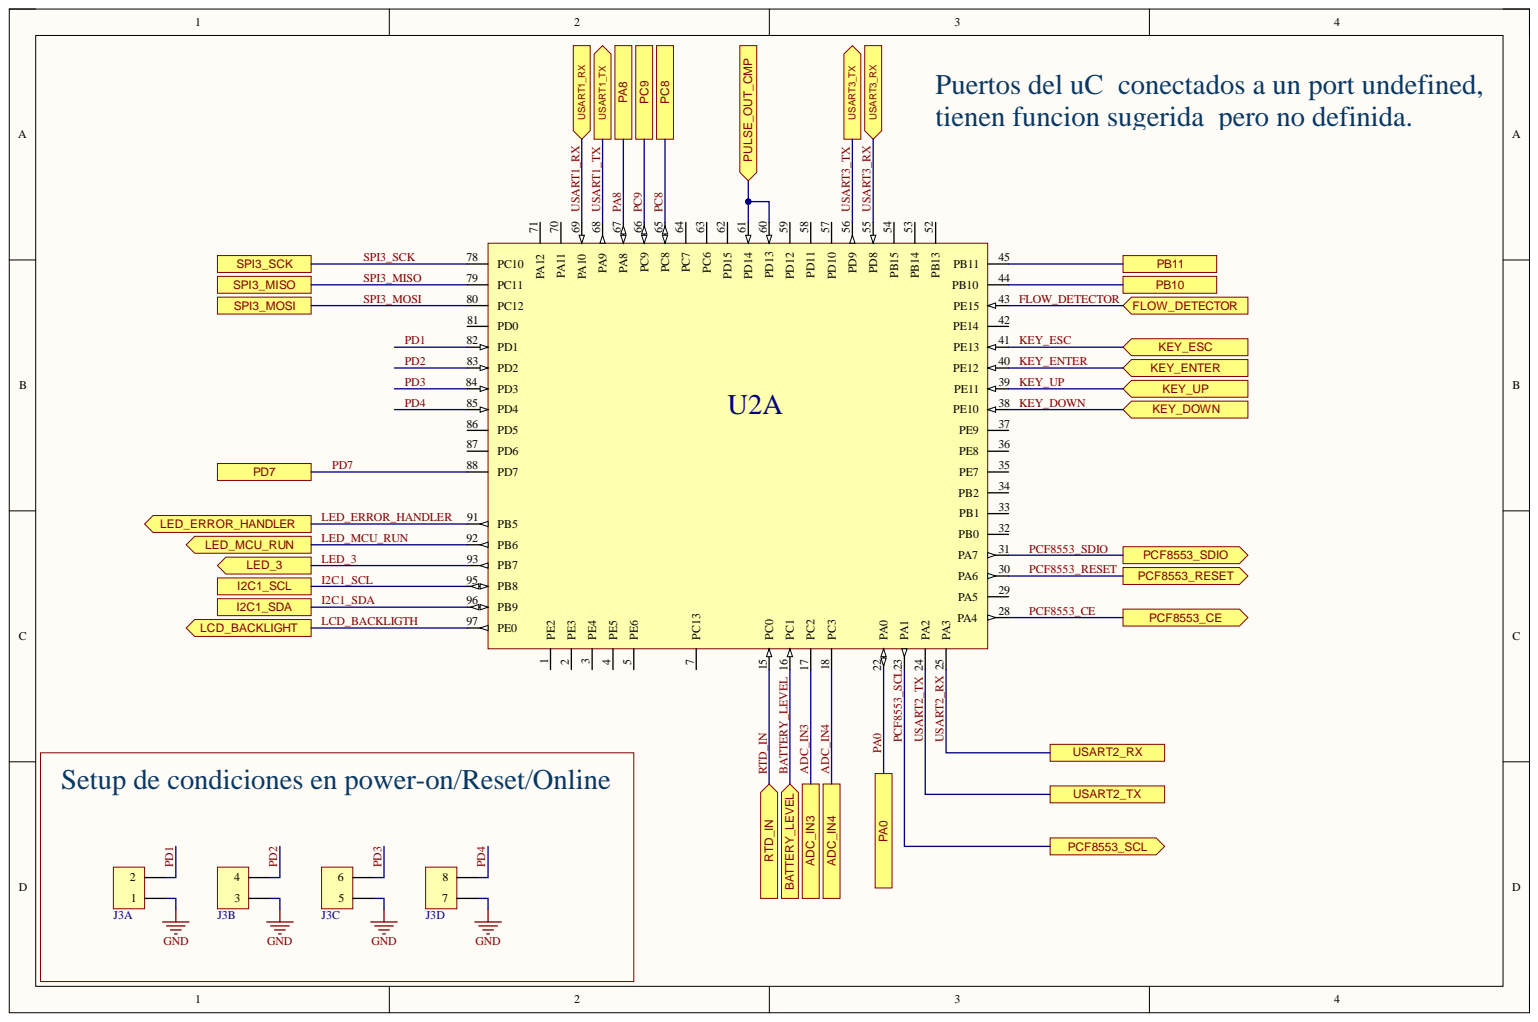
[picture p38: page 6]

USART3_RX
Puertos del uC conectados a un port undefined,
tienen funcion sugerida pero no definida.

Setup de condiciones en power-on/Reset/Online




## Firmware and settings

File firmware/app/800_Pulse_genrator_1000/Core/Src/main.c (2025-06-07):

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
/* Includes ------------------------------------------------------------------*/
#include "main.h"


void SystemClock_Config(void);
static void MX_GPIO_Init(void);
/**
  * @brief  The application entry point.
  * @retval int
  */
int main(void)
{

  /* MCU Configuration--------------------------------------------------------*/

  /* Reset of all peripherals, Initializes the Flash interface and the Systick. */
  HAL_Init();

  /* Configure the system clock */
  SystemClock_Config();

  /* Initialize all configured peripherals */
  MX_GPIO_Init();
  /* Infinite loop */
  /* USER CODE BEGIN WHILE */
  while (1)
  {

    while(HAL_GPIO_ReadPin(KEY_START_GPIO_Port, KEY_START_Pin));

    for(int n = 2000; n > 0; n--)
    {

      // Generador de 1 pulso
      if((n%1000) == 0)
      {
        HAL_GPIO_TogglePin(A0_1_GPIO_Port, A0_1_Pin);
      }

      // Generador de 10 pulsos
      if((n%100) == 0)
      {
        HAL_GPIO_TogglePin(A2_10_GPIO_Port, A2_10_Pin);
        HAL_GPIO_TogglePin(LED_GREEN_GPIO_Port, LED_GREEN_Pin);
      }

      // Generador de 1000 pulsos
      HAL_GPIO_TogglePin(A1_1000_GPIO_Port, A1_1000_Pin);
      HAL_Delay(1);
    }

    /* USER CODE END WHILE */

    /* USER CODE BEGIN 3 */
  }
  /* USER CODE END 3 */
}

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


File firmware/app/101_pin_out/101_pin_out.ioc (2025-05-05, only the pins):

Mcu.UserName=STM32U575VITxQ
PA0.Signal=GPIO_Analog
PA1.GPIO_Label=PCF8553_SCL
PA1.Signal=SPI1_SCK
PA10.Signal=USART1_RX
PA11.Signal=GPIO_Analog
PA12.Signal=GPIO_Analog
PA2.Signal=GPIO_Analog
PA3.Signal=GPIO_Analog
PA4.GPIO_Label=PCF8553_CE
PA4.Signal=GPIO_Output
PA5.Signal=GPIO_Analog
PA6.GPIO_Label=PCF8553_RESET
PA6.Signal=GPIO_Output
PA7.GPIO_Label=PCF8553_MOSI
PA7.Signal=SPI1_MOSI
PA8.GPIO_Label=MCX_ENABLE
PA8.Signal=GPIO_Output
PA9.Signal=USART1_TX
PB0.Signal=GPIO_Analog
PB1.Signal=GPIO_Analog
PB10.Signal=GPIO_Analog
PB11.Signal=GPIO_Analog
PB13.Signal=GPIO_Analog
PB14.Signal=GPIO_Analog
PB15.Signal=GPIO_Analog
PB2.Signal=GPIO_Analog
PB5.GPIO_Label=LED_ERROR
PB5.Signal=GPIO_Output
PB6.GPIO_Label=LED_ACTIVE
PB6.Signal=GPIO_Output
PB7.GPIO_Label=LED_SIGNAL
PB7.Signal=GPIO_Output
PB8.Signal=I2C1_SCL
PB9.Signal=I2C1_SDA
PC0.Signal=GPIO_Analog
PC1.Signal=GPIO_Analog
PC10.Signal=GPIO_Analog
PC11.Signal=GPIO_Analog
PC12.Signal=GPIO_Analog
PC13.Signal=GPIO_Analog
PC2.Signal=GPIO_Analog
PC3.Signal=GPIO_Analog
PC6.Signal=GPIO_Analog
PC7.Signal=GPIO_Analog
PC8.Signal=GPIO_Analog
PC9.Signal=GPIO_Analog
PD0.Signal=GPIO_Analog
PD1.GPIO_Label=DEBUG_LED
PD1.Signal=GPIO_Input
PD10.Signal=GPIO_Analog
PD11.Signal=GPIO_Analog
PD12.Signal=GPIO_Analog
PD13.Signal=LPTIM4_IN1
PD14.Signal=S_LPTIM3_CH1
PD15.Signal=GPIO_Analog
PD2.GPIO_Label=DEBUG_UART
PD2.Signal=GPIO_Input
PD3.GPIO_Label=SETUP_3
PD3.Signal=GPIO_Analog
PD4.GPIO_Label=SETUP_4
PD4.Signal=GPIO_Analog
PD5.Signal=GPIO_Analog
PD6.Signal=GPIO_Analog
PD7.Signal=GPIO_Analog
PD8.Signal=GPIO_Analog
PD9.Signal=GPIO_Analog
PE0.GPIO_Label=LED_BACKLIGHT
PE0.Signal=GPIO_Output
PE10.GPIO_Label=KEY_DOWN
PE10.Signal=GPXTI10
PE11.GPIO_Label=KEY_UP
PE11.Signal=GPXTI11
PE12.GPIO_Label=KEY_ENTER
PE12.Signal=GPXTI12
PE13.GPIO_Label=KEY_ESC
PE13.Signal=GPXTI13
PE14.Signal=SPI1_MISO
PE15.Signal=GPIO_Analog
PE2.Signal=GPIO_Analog
PE3.Signal=GPIO_Analog
PE4.Signal=GPIO_Analog
PE5.Signal=GPIO_Analog
PE6.Signal=GPIO_Analog
PE7.Signal=GPIO_Analog
PE8.Signal=GPIO_Analog
PE9.Signal=GPIO_Analog
PH3-BOOT0.Signal=GPIO_Analog

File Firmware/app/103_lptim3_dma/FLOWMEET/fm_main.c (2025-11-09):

/*
 * Computador de caudales -> Medición de frecuencia
 *
 * Originalmente se tenia:
 * El LPTIM 3 como fuente de reloj a LSE 32768Hz.
 * Canal 1 de LPTIM 3 modo captura, fuente LPTIM3 CH1->PD14.
 * La señal que ingresa al canal 1es onda cuadrada, desde el sensor primario.
 * El registro CCR1 debería tener siempre la ultima captura, lectura del reloj
 * que correo a 32768Hz.
 *
 * LPTIM 4, como contador de los pulsos del sensor primario.
 *
 * La idea es simple:
 * Esperamos un flanco descendente del sensor primario y
 * 1) Anotamos la captura del LPTIM 3
 * 2) Anotamos el contador del LPTIM 4
 *
 * Para tener buena resolución no medimos entre flancos, esperamos 1 segundo,
 * luego de un segundo esperamos el siguiente flanco.
 *
 * Los datos que tenemos son pulsos del sensor primario como un delta de pulsos
 * medidos en el LPTIM 4, su contador, y la cantidad de pulsos de 32768Hz entre
 * estos dos pulsos.
 *
 * El problema que se presente es que no su puedo hacer la captura funcionara
 * correctamente, capturaba bien para un numero de pulsos impares pero para
 * pulsos pares se congelaba el refresco de CCR1.
 *
 * ES INCREIBLE QUE EL MICROCONTROLADOR FALLLE DE ESTA FORMA, SE REQUIERE
 * INVESTIGACION ADICIONAL!!!!!!!!!!!!!!!!!!!!!!!!!!!!!
 *
 * Es importante notar que esto se da solamente si los pulsos que disparan la
 * captura se producen durante stop mode.
 *
 * Se deicidio cambiar el esquema a habilitar una interrupción, la de captura.
 * La interrupción de captura no se la puede dejar todo el tiempo habilitada,
 * despertaría al micro a la frecuencia de la señal del sensor primario. Es
 * suficiente con habilitar est cada un segundo, se obtienen los mismos datos
 * que se pretendían, con la penalidad de una salida de stop mode adicional
 * al refrescar los calor de captura en LPTIM 3 y contador en LPTIM 4.
 *
 * Autor: DHS
 * Fecha: 13/10/2024
 * Version 1:
 * Notas: Version inicial
 *
 *
 */

// Includes.
#include "fm_debug.h"
#include "fm_main.h"
#include "main.h"

// Typedef.

// Const data.

// Defines.

// Debug.

// Project variables, non-static, at least used in other file.

// External variables.
extern LPTIM_HandleTypeDef hlptim3;

static volatile uint32_t lptim3_capture_dma;


uint32_t freq;

// Private function prototypes.

// Private function bodies.

// Public function bodies.

/*
 * @brief   Loop infinito flowmeet.
 * @Note    El programa principal se desarrolla en este modulo. No escribir código en archivos.
 *          generados  por los IDEs.
 * @param   Ninguno.
 * @retval  Ninguno.
 *
 */
void FM_MAIN_Main()
{
  __HAL_RCC_LPTIM3_CLKAM_ENABLE();
  __HAL_RCC_LPTIM4_CLKAM_ENABLE();

  if (HAL_LPTIM_IC_Start_DMA(&hlptim3, LPTIM_CHANNEL_1, (uint32_t *)&lptim3_capture_dma, 1) != HAL_OK)
  {
    FM_DEBUG_UartUint32(0xDEADBEEF);
  }

  /*__HAL_DMA_DISABLE_IT(hlptim3.hdma[LPTIM_DMA_ID_CC1],
                       DMA_IT_TC | DMA_IT_HT | DMA_IT_DTE |
                       DMA_IT_ULE | DMA_IT_USE | DMA_IT_SUSP | DMA_IT_TO);
  HAL_NVIC_DisableIRQ(LPDMA1_Channel3_IRQn);
  HAL_NVIC_ClearPendingIRQ(LPDMA1_Channel3_IRQn);

  */

  HAL_Delay(100);

  for (;;)
  {
    uint32_t capture_copy = (lptim3_capture_dma & 0xFFFFu);
    FM_DEBUG_UartUint32(capture_copy);

    HAL_GPIO_WritePin(LED_ACTIVE_GPIO_Port, LED_ACTIVE_Pin, GPIO_PIN_RESET);
    HAL_SuspendTick();
    HAL_PWREx_EnterSTOP2Mode(PWR_STOPENTRY_WFI);
    HAL_ResumeTick();
    HAL_GPIO_WritePin(LED_ACTIVE_GPIO_Port, LED_ACTIVE_Pin, GPIO_PIN_SET);
  }
}

// Interrupts




/**
  * @brief  Wake Up Timer callback.
  * @param  hrtc RTC handle
  * @retval None
  */
void HAL_RTCEx_WakeUpTimerEventCallback(RTC_HandleTypeDef *hrtc)
{
  /* Prevent unused argument(s) compilation warning */
  UNUSED(hrtc);
  __HAL_LPTIM_CLEAR_FLAG(&hlptim3, LPTIM_FLAG_CC1);
}



/*** end of file ***/

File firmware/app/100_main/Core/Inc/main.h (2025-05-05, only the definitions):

#define PCF8553_SCL_Pin GPIO_PIN_1
#define PCF8553_SCL_GPIO_Port GPIOA
#define PCF8553_CE_Pin GPIO_PIN_4
#define PCF8553_CE_GPIO_Port GPIOA
#define PCF8553_RESET_Pin GPIO_PIN_6
#define PCF8553_RESET_GPIO_Port GPIOA
#define PCF8553_MOSI_Pin GPIO_PIN_7
#define PCF8553_MOSI_GPIO_Port GPIOA
#define KEY_DOWN_Pin GPIO_PIN_10
#define KEY_DOWN_GPIO_Port GPIOE
#define KEY_DOWN_EXTI_IRQn EXTI10_IRQn
#define KEY_UP_Pin GPIO_PIN_11
#define KEY_UP_GPIO_Port GPIOE
#define KEY_UP_EXTI_IRQn EXTI11_IRQn
#define KEY_ENTER_Pin GPIO_PIN_12
#define KEY_ENTER_GPIO_Port GPIOE
#define KEY_ENTER_EXTI_IRQn EXTI12_IRQn
#define KEY_ESC_Pin GPIO_PIN_13
#define KEY_ESC_GPIO_Port GPIOE
#define KEY_ESC_EXTI_IRQn EXTI13_IRQn
#define MXC_ON_Pin GPIO_PIN_8
#define MXC_ON_GPIO_Port GPIOC
#define MXC_ENABLE_Pin GPIO_PIN_8
#define MXC_ENABLE_GPIO_Port GPIOA
#define DEBUG_LED_Pin GPIO_PIN_1
#define DEBUG_LED_GPIO_Port GPIOD
#define DEBUG_UART_Pin GPIO_PIN_2
#define DEBUG_UART_GPIO_Port GPIOD
#define KEY_EXT_1_Pin GPIO_PIN_3
#define KEY_EXT_1_GPIO_Port GPIOD
#define KEY_EXT_1_EXTI_IRQn EXTI3_IRQn
#define KEY_EXT_2_Pin GPIO_PIN_4
#define KEY_EXT_2_GPIO_Port GPIOD
#define KEY_EXT_2_EXTI_IRQn EXTI4_IRQn
#define LED_ERROR_Pin GPIO_PIN_5
#define LED_ERROR_GPIO_Port GPIOB
#define LED_ACTIVE_Pin GPIO_PIN_6
#define LED_ACTIVE_GPIO_Port GPIOB
#define LED_SIGNAL_Pin GPIO_PIN_7
#define LED_SIGNAL_GPIO_Port GPIOB
#define LED_BACKLIGHT_Pin GPIO_PIN_0
#define LED_BACKLIGHT_GPIO_Port GPIOE

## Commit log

2025-05-05 Chore - Cambio presentacion de version a 00.00.001 BT
2025-05-05 chore - cambios menores
    Se modifica estructura de changelog.md
2025-05-05 chore - cambios menores
    Se hicieron algunos test visuales al funcionamiento de equipo, se hace un commit para pratcticar como se ve el commit en las diferentes herramientas.
2025-05-11 refactor: cambia modo en que se maneja tiempo a idel del RTOS
    [02 - Matriz de caracteristicas.xlsx]
2025-05-11 fix: corrige reinicio inesperado al salir del menú (detectado en pruebas beta)
    [fm_main.c]
2025-05-13 doc: registra merge de release/firmware-01.01.009-B0 a develop (fast-forward)
    Se quiere continuar desarrollando mientras produccion valida 01.01.009-B0
2025-05-17 docs: inicia sección UNRELEASED tras erroes que euncuentra produccion en tag v01.01.009-B0
2025-05-17 refactor: se actualiza la forma en que se refresca la pantalla, correccion de bug version beta.
    [fmx.c]
2025-05-17 fix: se solucionan bugs introducidos en el commit anterior.
2025-05-17 Chore: guardo cambios para hacer un merge a develop
2025-06-07 [FIRMWARE] Release candidato aprobado: 01.01.009-beta3 final
    quedaron algunaso observaciones, pero es aceptable para enviar a produccion.
2025-06-07 [FIRMWARE] Chore: ajusto version de presentacion a 01.01.010-D0, beta 0 en desarrollo
2025-06-20 [Firmware] Chore: hago commit con tareas intermedias para salvar el trabajo y hacer pruebas en otras ramas.
    [08 - Logger consumo y capacidad.xlsx]
2025-07-24 {GLOBAL} Refactor
    Se pretende usar nuevamente el CubeMX. esto puede traer problemas, por eso hago un commit, puede que no vuelva a funcionar.
    [fm_init.c, fmx.c, main.c]
2025-08-06 release beta: v01.01.10 b0 - para que teste producción
2025-09-13 [DOCS} contributing_firmware
    Actualizo archivo que regula como contribuir en el proyecto.
2025-09-20 {DOCS] Cambio la esctructura completa de carpetas - Comienzo a usar Codex + VSCode
    [01_NON_RECURRING_ENGINEERING.xlsx, 02 - Matriz de caracteristicas.xlsx, 02_matriz_de_caracteristicas.xlsx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]
2025-11-09 [DOCS] docs(contrib): alinea estilo IA y renombra carpetas
    [01_NON_RECURRING_ENGINEERING.xlsx, 01_componentes_check_list.xlsx, 01_pcb_check_list.xlsm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]

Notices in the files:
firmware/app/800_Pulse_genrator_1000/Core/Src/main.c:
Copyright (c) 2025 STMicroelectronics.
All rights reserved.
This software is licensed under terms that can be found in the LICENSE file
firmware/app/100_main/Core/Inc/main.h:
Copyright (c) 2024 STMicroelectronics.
